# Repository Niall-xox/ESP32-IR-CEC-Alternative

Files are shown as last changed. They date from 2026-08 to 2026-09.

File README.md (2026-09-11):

# ESP32 IR Remote

A USB stick that makes your TV follow your PC's power state. The PC sleeps, the
TV turns off. The PC wakes, the TV turns on.

It is a replacement for HDMI-CEC on machines where CEC does not work — which is
most PCs. If you use a TV as a monitor and are tired of reaching for the remote
every time the machine wakes, this fixes that.

```
  PC                                  ESP32-S3 stick               TV
  ──                                  ─────────────                ──
  daemon  ──── USB HID ────────────►  firmware  ──── IR LED ────►
  (background service)                (Arduino)      (infrared)
```

A small background service on the PC watches for power events and sends `ON` or
`OFF` over USB. The stick blinks the matching infrared code at the TV, exactly
as the TV's own remote would. The stick appears as a standard USB HID device, so
there is no driver to install on any OS.

**The rule it follows:** the TV mirrors what your PC's own screen is doing. If
the display is on, the TV is on. If the display sleeps, blanks or shuts down,
the TV goes off.

---

## Status

Working and in daily use, but not yet released — read this before relying on it.

| | |
|---|---|
| **Linux** | Well tested. Sleep, wake, shutdown and boot all verified on hardware |
| **Windows** | Builds and runs as a service, tested less. Some paths unverified |
| **TV profiles** | LG is verified on real hardware. Samsung, Sony and Toshiba are derived from published code databases but **untested** |
| **Releases** | None tagged yet. Build from source for now |
| **USB ID** | Currently `1209:0001`, a shared *test* ID. A permanent one will be applied for; see [`brief.md`](brief.md) §2 |

---

## Hardware

| Part | Notes |
|---|---|
| **ESP32-S3 SuperMini** | Must be an S3 or S2 — native USB is required. A classic ESP32, ESP8266 or C3 **will not work** |
| **KY-005 IR LED module** | Any 940nm IR LED module. A bare LED with a resistor works too |
| **SSD1306 OLED, 128×32, I²C** | Optional but recommended — it is how you see which profile is active |
| **Momentary push button** | Any. Wired to ground; the internal pull-up is used |

### Wiring

| Signal | GPIO |
|---|---|
| IR LED data | 4 |
| OLED SDA | 2 |
| OLED SCL | 3 |
| Button | 5 → GND |

The OLED is addressed at `0x3C`. All pins are set in `firmware/src/main.cpp` — a
different board only needs those four constants changed.

### Enclosure

FreeCAD sources are in `hardware/`. `ESP32-Remote-Housing.FCStd` is the editable
master; the `.step` files are supplier models of the components, for fit
checking. Mesh exports are not tracked — export your own STL from the FCStd.

---

## Flashing the firmware

Needs [PlatformIO](https://platformio.org/install/cli).

```bash
git clone https://github.com/Niall-xox/ESP32-IR-CEC-Alternative
cd ESP32-IR-CEC-Alternative/firmware

pio run -t upload      # the firmware
pio run -t uploadfs    # the web config UI — needed once
```

Both steps are required on a fresh board. `uploadfs` writes the configuration
page into the stick's filesystem; without it the web UI will 404.

Some boards need a button combination to enter download mode before flashing,
and do not leave it automatically afterwards — if the device does not reappear
after `upload`, press reset or replug it.

> **`uploadfs` erases saved profiles.** It rewrites the whole filesystem, so any
> IR codes you have entered are lost and the defaults come back. That is useful
> for a clean slate and unwelcome otherwise. Firmware-only updates (`upload`)
> leave your profiles alone.

---

## Installing the daemon

### Linux — from source

```bash
cmake -B daemon/build -S daemon -DCMAKE_INSTALL_PREFIX=/usr
cmake --build daemon/build
sudo cmake --install daemon/build
```

Requires `sdbus-c++` **2.x**, `hidapi` and `libudev` (the development package —
the library itself ships with systemd, so it is already installed).

> **`-DCMAKE_INSTALL_PREFIX=/usr` is not optional.** The default prefix is
> `/usr/local`, which puts the udev rule in `/usr/local/lib/udev/rules.d/` and
> the service in `/usr/local/lib/systemd/system/`. Neither udev nor systemd
> looks in those directories, so the install appears to succeed and then the
> daemon cannot open the device and `systemctl enable` cannot find the unit.

Then create the service account the unit runs as, and let udev pick up the new
rule:

```bash
sudo groupadd --system esp32ir
sudo useradd --system --no-create-home --shell /usr/sbin/nologin \
             --gid esp32ir esp32ir
sudo udevadm control --reload-rules
sudo udevadm trigger --subsystem-match=hidraw --action=add
sudo systemctl enable --now esp32-ir-remote
```

Check it worked — the stick's node should be group `esp32ir`:

```bash
ls -l /dev/hidraw*
journalctl -u esp32-ir-remote -f
```

### Linux — packages

`.deb` and `.rpm` are built for each release, and handle the account, udev rule
and service for you.

> **The `.deb` needs sdbus-c++ 2.x, which Ubuntu 24.04 LTS does not have** — it
> ships 1.4.0. The package installs on Debian 13+ and Ubuntu 25.04+. On 24.04,
> build from source.

**Arch** builds from source on your machine:

```bash
cd daemon/packaging && makepkg -si
```

This fetches the `v$pkgver` git tag, so it only works once a release has been
tagged — see *Status* above.

**NixOS** — add the flake and enable the module:

```nix
inputs.esp32-ir-remote.url = "github:Niall-xox/ESP32-IR-CEC-Alternative";

# then
imports = [ inputs.esp32-ir-remote.nixosModules.default ];
services.esp32-ir-remote.enable = true;
```

The module declares the user, udev rule and service for you.

### Windows

Needs Visual Studio Build Tools and `hidapi` from vcpkg.

```powershell
cmake -B daemon/build -S daemon `
      -DCMAKE_TOOLCHAIN_FILE=<vcpkg>/scripts/buildsystems/vcpkg.cmake
cmake --build daemon/build --config Release
```

Then from an **elevated** PowerShell:

```powershell
powershell -ExecutionPolicy Bypass -File .\daemon\packaging\windows\install-service.ps1 `
           -BinaryPath <path>\esp32-ir-daemon.exe
```

The daemon must run as a Windows Service — a normal program is not sent power
events at all. The installer registers it, sets restart-on-failure and creates
the log directory. Logs go to `C:\ProgramData\ESP32IRRemote\daemon.log`.

To check the stick is reachable without installing anything, run the binary with
`--console`.

---

## Using it

### The button

One button, four gestures, by how long you hold it:

| Hold | Result |
|---|---|
| Tap | Wake the screen. Tap again to switch to the next TV profile |
| ~1–4 s | Nothing — a bar fills, one block per second. Let go to cancel |
| **4–7 s** | **Enter or leave wireless config mode** |
| 7–16 s | Nothing — the reset bar fills. Let go to cancel |
| **Past 16 s** | **Factory reset** — restores the default profiles |

When the screen is off, the first tap only wakes it; the *next* tap changes
profile. That stops a blind press in the dark silently switching TVs.

### The screen

Shows the active profile, `TV On` / `TV Off` when a command arrives, and
`Not Configured` if the selected profile has no IR code. It blanks after two
seconds unless you turn on "display always on" in the web UI.

### Configuring it

Hold the button for 4–7 seconds. The stick starts its own WiFi access point:

- **Network:** `ESP32-IR-Remote`
- **Password:** `irremote123`
- **Address:** shown on the OLED

Connect and open that address in a browser. You can add, edit and delete TV
profiles, set the active one, toggle the always-on display, and factory reset.
Hold the button 4–7 seconds again to exit — power syncing keeps working while
the config page is up.

---

## TV profiles and IR codes

A **profile** is one TV: a name, an IR protocol, and two codes — one to turn the
TV on, one to turn it off. Four ship by default, and all four transmit:

| Profile | Protocol |
|---|---|
| LG | NEC |
| Samsung | Samsung |
| Sony | Sony |
| Toshiba | NEC |

If your TV is not listed, add it through the web UI. You will need two things:
the **protocol** and the two **codes**.

### Discrete codes, not toggle codes

This is the part that trips people up. Most remotes send a single *toggle* code
for power — press it and the TV flips state. That is no use here: if the TV and
PC ever fall out of sync, every command makes it worse.

You need **discrete** codes — a separate "power on" and "power off". Most TVs
understand them even though their own remote never sends them, which is why you
have to look them up rather than copy them off the remote in front of you.

### Where to find them

[**irdb**](https://github.com/probonopd/irdb) is the best starting point. Browse
`codes/<Brand>/TV/` and look for `POWER ON` and `POWER OFF` entries:

```
POWER ON/OFF,Sony12,1,-1,21
POWER ON,Sony12,1,-1,46
POWER OFF,Sony12,1,-1,47
```

[**RemoteCentral**](https://files.remotecentral.com/library/index.html) has
curated discrete codes for brands irdb lacks.

Two warnings from experience. **Some brands have no discrete codes at all** —
TCL and Hisense are the notable ones, which is why they are not shipped as
profiles. And **never put a toggle code in both fields**; the TV would flip on
every single command.

Converting a database entry into the hex the firmware wants is fiddly. The
method, including how to check a code before trusting it, is written up in
[`brief.md`](brief.md) under *Where IR codes come from*.

---

## Troubleshooting

**The daemon says "ESP32 not connected".** Check the stick enumerates —
`lsusb` should show `1209:0001`. On Linux, check `/dev/hidraw*` for a node owned
by group `esp32ir`; if it is `root:root`, the udev rule has not been applied.
Replug the stick after installing.

**The TV does nothing but the daemon reports success.** The IR code was
transmitted but your TV did not accept it — usually the wrong profile, or codes
that do not match your model. Try aiming the stick directly at the TV's sensor;
IR needs line of sight.

**The screen says `Not Configured`.** The active profile has no code for that
direction. Add one through the web UI.

**Nothing happens on sleep.** Check the service is running:
`systemctl status esp32-ir-remote`, or on Windows look at
`C:\ProgramData\ESP32IRRemote\daemon.log`.

---

## Licence

**GPL-3.0-or-later.** See [LICENSE](LICENSE).

This covers everything in the repository, including the enclosure design in
`hardware/`.

Built on these, with thanks:

| Project | Licence |
|---|---|
| [IRremoteESP8266](https://github.com/crankyoldgit/IRremoteESP8266) | LGPL-2.1 |
| [ArduinoJson](https://arduinojson.org/) | MIT |
| [Adafruit SSD1306 / GFX](https://github.com/adafruit/Adafruit_SSD1306) | BSD |
| [hidapi](https://github.com/libusb/hidapi) | BSD / GPL-3 / HIDAPI |
| [libudev](https://github.com/systemd/systemd) (systemd) | LGPL-2.1 |
| [sdbus-c++](https://github.com/Kistler-Group/sdbus-cpp) | LGPL-2.1 |
| [irdb](https://github.com/probonopd/irdb) | IR code database |

---

## More detail

[`brief.md`](brief.md) is the working document — how the two halves talk to each
other, why the design decisions were made, what is verified and what is not, and
what is still outstanding. Read that before changing anything.

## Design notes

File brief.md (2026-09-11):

# ESP32 IR Remote — Project Brief

A USB stick that makes a TV follow a PC's power state. The PC sleeps, the TV
turns off. The PC wakes, the TV turns on. It is a replacement for HDMI-CEC on
machines where CEC does not work, which is most PCs.

This file is the single source of truth for how the project works and where it
stands. It is meant to be read start to finish in about fifteen minutes.

---

## 1. The shape of the thing

Two pieces of software, one cable between them.

```
  PC                                  ESP32-S3 stick                TV
  ──                                  ─────────────                 ──
  daemon  ──── USB HID ────────────►  firmware  ──── IR LED ─────►
  (a background service)              (Arduino)      (infrared)
```

**The daemon** is a small background program on the PC. Its only job is to
notice power events — sleep, wake, shutdown, boot — and send the word `ON` or
`OFF` down the USB cable.

**The firmware** runs on the ESP32. It listens on USB, and when it hears `ON` or
`OFF` it blinks the matching infrared code at the TV, exactly the way the TV's
own remote would. It also drives a small OLED screen and one button, and can put
up a WiFi configuration page.

Neither side knows anything about the other beyond those two words and a reply.

### Where things live

```
README.md  LICENSE  VERSION  brief.md  flake.nix
firmware/          the ESP32 side — src/, data/ (the web UI), platformio.ini
daemon/            the PC side — src/, packaging/, CMakeLists.txt
hardware/          FreeCAD enclosure and supplier part models
tools/hid-test/    a minimal HID echo, for when a board will not talk at all
.github/workflows/ builds both halves on every push; packages on a v* tag
```

`VERSION` sits at the root rather than under `daemon/` because the two halves
share a wire protocol and must ship together — there is one version and it
belongs to the device. `CMakeLists.txt`, `flake.nix` and `PKGBUILD` all read it
from there.

No path in the repository contains a space, which is deliberate: every script,
CMake path and CI step would otherwise need quoting, and the one that gets
forgotten fails in a way that is tedious to trace.

### The one idea the whole project rests on

**The TV mirrors what the PC's own screen is doing.**

That is the rule, and everything else follows from it. If the PC's display is
on, the TV should be on. If the display goes off — because you asked it to,
because the machine idled out, because it went to sleep or shut down — the TV
should be off. It is the same behaviour a CEC-connected display gives you, which
is the point: this device exists because CEC usually is not available on a PC.

### Why USB HID and not a serial port

HID (Human Interface Device) is the USB class that keyboards and mice use. The
advantage is that **every OS already has a driver for it**. Plug the stick in
and it works — no COM port to pick, no driver to install, nothing to sign on
Windows. That is why the project moved from serial to HID.

The cost is that the ESP32 has to have native USB hardware. The ESP32-S3 does,
and so does the S2. The ESP32-C3 does **not** (its USB controller only does
serial/JTAG, not arbitrary HID), and neither do the classic ESP32 or the
ESP8266. A serial version existed once and was removed; git history has it if
it is ever wanted again — see §11.

---

## 2. Hardware

| Part | Notes |
|---|---|
| ESP32-S3 SuperMini | Native USB. Any S3 board works; pins are set in code, not by the board profile. |
| KY-005 IR LED module | On GPIO 4. |
| SSD1306 OLED, 128×32, I²C | SDA GPIO 2, SCL GPIO 3, address 0x3C. |
| Push button | GPIO 5, to ground (uses the internal pull-up). |

CAD for the enclosure is in `hardware/`. The `.FCStd` is the editable master;
`.stl` exports are deliberately not tracked in git.

### The USB identity, and why it is `1209:0001`

Every USB device announces a **vendor ID** and a **product ID**. Vendor IDs come
from the USB-IF and cost real money. `0x1209` is **pid.codes**, a vendor ID held
in trust for open-source hardware and given out free; `0x0001` under it is their
designated **test PID**, for a device that has not been allocated one of its own
yet. Getting a real product ID is therefore a **PID-only** change — the vendor
half never moves.

**The caveat, in their words.** pid.codes state that `1209:0001` "is reserved
for use in private testing. Anyone may assign it to their device while they're
testing in-house, but it MUST NOT be used on any device that will be
redistributed, sold, or manufactured."

That is a prohibition, not a preference — and it binds on redistributing a
**device**. A GitHub Release here ships daemon packages, not hardware, and the
only stick carrying `1209:0001` is the author's own. Publishing on it was
weighed and accepted on that basis (§9), and stops being defensible the moment
sticks are handed to other people.

**Applying is not blocked on anything.** pid.codes want only a public source
repository under an open-source licence, which now exists — so the pull request
can go in at any time. PIDs `0x0000`–`0x1FFF` are reserved, so the allocated
number will be `0x2000` or above. Do not substitute a made-up number while
waiting: that squats on a registry which may legitimately assign it to somebody
else, in the namespace you are about to ask a favour from.

The value lives in **five** hand-kept places, which must change together:

| File | Spelling |
|---|---|
| `firmware/src/main.cpp` | `0x1209` / `0x0001` |
| `daemon/src/main.cpp` | `0x1209` / `0x0001` |
| `daemon/99-esp32-ir-remote.rules` | `"1209"` / `"0001"` (lowercase, no `0x`) |
| `daemon/packaging/windows/install-service.ps1` | `"1209"` / `"0001"` |
| `daemon/packaging/windows/verify-windows.ps1` | `"1209"` / `"0001"` |

Five copies is itself the argument for generating them from one source — §9.

---

## 3. The conversation over USB

Every exchange is one message and one reply, in fixed-size 64-byte packets.

**PC → ESP32:** `[sequence byte][ "ON" or "OFF" ][zero padding...]`

**ESP32 → PC:** `[same sequence byte][ "ACK" or "ERR" ][zero padding...]`

The **sequence byte** is a counter that increments on every command (1…255, then
back to 1). The reply carries the same number back, and the daemon ignores any
reply carrying a different one.

It exists to catch one specific race. The daemon sends `OFF`; USB is
re-enumerating, so the reply is slow; the daemon gives up and reports failure.
The ESP32 *did* receive it, transmits, and queues an `ACK` that is now in
flight. The next event sends `ON` — and without the sequence byte the daemon
would read that stale `ACK`, believe `ON` was confirmed, and log a success that
never happened. One byte on the wire prevents it.

`ACK` means **the infrared signal was actually transmitted**. `ERR` means it was
not, which in practice means the active profile has no code stored for that
direction. Both are useful: the daemon treats them the same way (the command
failed), but `ERR` arrives instantly and says *why*, instead of looking
identical to a broken cable for two seconds.

### One timeout, and failing fast when nothing is plugged in

A send gets **2 seconds** — total, covering opening the device, any retried
write, and waiting for the reply. There is one number, in
`HIDTransport.cpp`, and nothing else tunes it. A healthy round trip takes well
under 200 ms, and every deadline an OS imposes on us is longer than 2 s.

The more important rule is what happens when the stick is **not connected**:

- **Nothing enumerated** → give up immediately. There is nothing to wait for.
- **A handle we had just stopped working** → retry until the deadline, because
  the device demonstrably exists and is probably re-enumerating.
- **A command owed to a device that has not arrived yet** → not the transport's
  problem. It waits for the arrival notification in §5, never on a timer.

That distinction is what lets you leave the daemon installed with the stick
unplugged and have sleep and shutdown behave completely normally. Without it,
the daemon sits polling for a device that will never appear, holding the machine
up every single time.

---

## 4. The firmware (`firmware/`)

Five modules, about 1,250 lines.

| File | Does |
|---|---|
| `main.cpp` | USB HID device, IR sending, the WiFi config web server, and the wiring between button, display and storage. |
| `Profiles.cpp/.h` | The TV profiles and settings, and reading/writing them to flash. |
| `Display.cpp/.h` | Everything drawn on the OLED, and the timers that blank it. |
| `Button.cpp/.h` | Turns raw pin readings into press / hold / release events. |
| `HoldTimings.h` | The four hold durations, in one place. |

### Profiles

A **profile** is one TV: a name, an IR protocol (NEC, Samsung or Sony), an ON
code, an OFF code, and a "visible" flag that controls whether the button cycles
through it.

Four ship by default, and **every one of them transmits**. Up to 32 profiles.

| Profile | Protocol | ON | OFF |
|---|---|---|---|
| LG | NEC | `0x20DF23DC` | `0x20DFA35C` |
| Samsung | SAMSUNG | `0xE0E09966` | `0xE0E019E6` |
| Sony | SONY | `0x00000750` | `0x00000F50` |
| Toshiba | NEC | `0x02FD7E81` | `0x02FDFE01` |

That is the rule for the factory default: a brand earns a place only once a
discrete on/off pair exists that covers the product line rather than one model.
A default profile that cannot work is worse than no profile, because it looks
like the device supports your TV.

**TCL and Hisense are therefore absent, not blank.** Neither publishes usable
discrete codes: TCL has only a power *toggle*, in a protocol this firmware does
not speak, and Hisense is not in irdb at all. Filling them with a toggle would
be worse still — the same code in both fields flips the TV on every command,
which is the drift discrete codes exist to prevent. Owners of those sets add a
profile through the web UI instead.

That difference is structural, not bad luck. LG, Samsung, Sony and Toshiba
design their own remotes across a whole product line, so one code set covers the
brand. TCL and Hisense are assemblers — the same model number ships as a Roku TV
in one market and a Google TV in another, with different remotes.

The *Not Configured* path still exists and still matters: it catches a
user-added profile saved with one or both codes blank.

**Changing the defaults does not change a device that has already booted.**
`Profiles::begin()` writes them only when `profiles.json` is absent, so picking
up a new default set needs a factory reset — hold the button past 16 s.
Re-flashing alone is not enough.

**Only LG is proven on hardware.** The other three are derived from corroborated
sources and cross-checked against the encoder, but nobody has pointed the stick
at a Samsung, Sony or Toshiba. Two known risks:

- **Samsung deep sleep.** There are reports that Samsung's discrete power-on
  stops working once the TV has been off for a long time — the set stops
  listening to IR. If true, that hits this project's main use case directly
  (PC wakes in the morning, TV does not). Unconfirmed, and worth being the first
  thing checked if a Samsung ever turns up.
- **Samsung's discrete pair is not in irdb**, which lists only the toggle. It
  comes from RemoteCentral instead and derives consistently to the published
  hex, but it is one source rather than two.

Codes are stored on the ESP32's own flash filesystem (LittleFS) as two JSON
files: `/profiles.json` and `/settings.json`. Writes go to a `.tmp` file first,
are length-checked, and only then renamed over the real file.

The length check is not about validating what you typed — it catches a
*truncated* write, from the flash filling up or power being cut mid-write.
Without it the atomic rename would atomically install a valid-looking but
unparseable file, and every IR code you had entered would be gone on the next
boot.

### Discrete vs toggle codes

Most TV remotes send one *toggle* code for the power button — press it and the
TV flips state. That is useless here, because if the TV and PC ever drift out of
sync every command makes it worse.

This project needs **discrete** codes: a separate "power on" code and "power
off" code. Most TVs understand them even though their own remote never sends
them, which is why the codes have to be looked up rather than copied off the
remote in front of you.

A useful consequence: repeat commands are always safe. Sending `OFF` to a TV
that is already off does nothing at all. The daemon never has to track what it
last sent, and never has to decide whether a command is redundant.

### Where IR codes come from

Kept here because finding these again from scratch is slow, and because getting
a code wrong is worse than having none.

**[irdb](https://github.com/probonopd/irdb)** is the one to reach for first —
the largest crowd-sourced database, and it stores codes as *protocol, device,
subdevice, function* rather than as raw hex, which is exactly what you need.
Browse `codes/<Brand>/TV/` and read the CSVs:

```
curl -s https://api.github.com/repos/probonopd/irdb/contents/codes/Sony/TV
curl -s https://cdn.jsdelivr.net/gh/probonopd/irdb@master/codes/Sony/TV/1,-1.csv | grep -i power
  POWER ON/OFF,Sony12,1,-1,21
  POWER ON,Sony12,1,-1,46
  POWER OFF,Sony12,1,-1,47
```

Two things that reads out at a glance: whether **discrete** on/off codes exist
at all (many brands only have a toggle), and **how many code sets** the brand
has. One code set for a whole brand means one consistent scheme and good
coverage; five means it varies by model and you should not ship a guess.

**Turning those parameters into the hex the firmware wants.** Do *not* copy hex
off a forum — convert from the protocol parameters using the same encoder the
firmware links against, so the bit ordering cannot disagree:

- NEC — `IRsend::encodeNEC(address, command)` in `ir_NEC.cpp`
- Sony — `IRsend::encodeSony(nbits, command, address, extended)` in `ir_Sony.cpp`

Both live in `firmware/.pio/libdeps/lolin_s3_mini/IRremoteESP8266/src/`. They are
small and pure, so the quickest check is to copy them into a throwaway C file and
print the values.

**Sanity-check any result two ways.** Run the brand's *toggle* code through the
same path and confirm it matches a value you can find independently — Sony's
toggle should come out `0xA90`, LG's ON should come out `0x20DF23DC`, which is
the code already proven on real hardware here. If the toggle reproduces, the
encoding is right and the discrete pair can be trusted.

**Other sources**, in rough order of usefulness:

- [RemoteCentral's discrete code library](https://files.remotecentral.com/library/index.html)
  — curated per brand, and the best source for discrete codes irdb lacks. This
  is where the Samsung discrete pair came from; irdb only lists Samsung's toggle.
- [SB-Projects protocol reference](https://www.sbprojects.net/knowledge/ir/sirc.php)
  — how the protocols are actually framed. Read this when a code looks right but
  does not work; the Sony 12/15/20-bit distinction is the classic trap.
- The Flipper Zero and LIRC remote databases, and manufacturer RS-232/IR PDFs
  (Hisense publish one) — worth a look, but model-specific far more often.

**Watch out for.** Forum hex with no protocol stated (unusable — you cannot tell
12-bit Sony from 20-bit). Single-model blog posts presented as brand-wide. And
NEC codes whose checksum does not validate: in NEC the second command byte is
the bitwise inverse of the first, so `0x…8B75` is wrong on its face because
`0x8B` inverts to `0x74`. That one check rejects a surprising amount of bad data.

### The button

One button, four things, decided by how long you hold it:

| Hold for | On release |
|---|---|
| under 0.3 s | **Press** — wake the screen; press again to cycle to the next visible profile |
| 0.3 – 4 s | Nothing (you changed your mind — the screen shows a filling bar as a countdown) |
| 4 – 7 s | **Toggle WiFi config mode** on or off |
| 7 – 16 s | Nothing (again, a bar shows how far you are) |
| held past 16 s | **Factory reset** — fires while still held, not on release |

The press behaviour has one subtlety worth knowing: when the screen is off, the
*first* press just wakes it and shows the current profile, and only the next
press cycles. When "display always on" is enabled the screen never sleeps, so
every press cycles. That is deliberate — it stops a blind press in the dark
silently changing which TV you are controlling.

All four durations live in `HoldTimings.h` and are used from there.

### The watchdog

The ESP32 has a hardware timer that reboots the chip if the firmware stops
feeding it. `loop()` feeds it on every pass, so if `loop()` ever stops running —
a hang, a deadlock, a wait that never returns — the device resets itself after
**20 seconds** and comes back working.

This matters more than it sounds. A hung stick and an unplugged stick look
identical from the PC: the daemon just sees a command that got no reply. So
without the watchdog a hang would sit there until somebody noticed the TV had
stopped following the PC — which is exactly the unreliability this device exists
to beat. A reset costs nothing: profiles live in flash, and the daemon reopens
the device on its next command.

The 20 seconds is set by the **web server**, not by anything in our own code.
Serving the config page can legitimately block for around 12 s inside one pass
of `loop()` if a browser stalls mid-request (the server waits 5 s for the
request, 5 s for data to be acknowledged and 2 s for the close). Everything else
— button, display, IR, USB — is under 200 ms. The generous margin is deliberate:
a false reset while somebody is saving IR codes would be worse than a slow one.

It is armed at the very end of `setup()`, so start-up is never watched. A hang
before that point is a bricked-at-boot device you find the moment you flash it,
and leaving setup out keeps first-boot flash formatting from having to fit
inside the timeout.

### The OLED

Shows the active profile. By default it blanks after 2 seconds; "display always
on" keeps it lit. It also shows: `TV On` / `TV Off` confirmations when a command
arrives, the two hold progress bars, `Not Configured` when a profile has no
code, and — in WiFi mode — the AP's IP address.

**The progress bars are one block per second**, and the block count is derived
from the thresholds in `HoldTimings.h` rather than written down separately — so
the hold bar has 4 blocks and the reset bar 9, and both follow automatically if
a timing changes. That makes them countable rather than merely watchable: four
blocks means four seconds.

Each bar stops one block short of full, because the moment it would complete is
the moment the screen changes — to *Release To Enter Wireless Config!* at 4 s,
and to the status screen when the reset fires at 16 s. The screen changing is
the completion signal.

### WiFi config mode

Hold the button 4–7 seconds and the ESP32 starts its own WiFi access point:

- SSID `ESP32-IR-Remote`, password `irremote123`
- Browse to the IP shown on the OLED

The page lets you add, edit, delete and reorder profiles, set the active one,
toggle "display always on", and factory reset. It is served from LittleFS
(`firmware/data/index.html`, uploaded with `pio run -t uploadfs`).

The AP is transient and user-initiated — it is not running unless you asked for
it. Power syncing keeps working normally while it is up.

---

## 5. The daemon (`daemon/`)

About 1,450 lines of C++, one binary, built with CMake. It is built around two
small interfaces, which is what keeps Linux and Windows from tangling:

- **`ITransport`** — "send this command, tell me if it was confirmed."
  `HIDTransport` is the only implementation and is shared by both platforms.
- **`IPowerMonitor`** — "watch the OS and call me when the TV should change."
  `LinuxPowerMonitor` and `WindowsPowerMonitor` implement it.

`main.cpp` picks the right monitor for the platform and connects them. That
split is why Windows support could be added later without disturbing Linux.

### Linux (`LinuxPowerMonitor`, ~235 lines)

Linux makes this easy. `systemd-logind` broadcasts `PrepareForSleep` and
`PrepareForShutdown` over D-Bus, and — crucially — lets a program take an
**inhibitor lock** that *delays* the sleep until it says it is ready.

So the sequence is honest end to end:

```
sleep requested → daemon sends OFF → ESP32 transmits IR → ACK
               → daemon releases the lock → machine sleeps
```

The TV is genuinely off before the PC goes down.

**The lock has to be taken in advance — that is the API, not a choice we made.**
`PrepareForSleep(true)` is not a request you can answer; it is an announcement
that the delay window has already opened. logind collects who holds delay locks,
*then* broadcasts, *then* waits for those specific file descriptors to close. A
program that was not already holding one is not on the list being waited for. So
the daemon takes the lock at startup and re-takes it on every wake.

**Boot is handled separately, and waits for the stick.** The daemon reaches
`multi-user.target` before the ESP32 has finished enumerating — the stick is
powered by the machine that is booting, so it is running its own `setup()` while
systemd is starting us. The `ON` it owes has nowhere to go yet.

Rather than retry on a timer, the daemon subscribes to **udev** and is told when
a matching hidraw node appears. That is the same kind of doorbell it already
uses for sleep, so `run()` waits on both at once with `poll()` rather than
`enterEventLoop()`. If the udev watch cannot be set up it falls back to
`enterEventLoop()` and the sleep path is unaffected.

**The unit sandbox has to allow `AF_NETLINK`.** The udev monitor is a netlink
socket, and `RestrictAddressFamilies=AF_UNIX` — which was correct when D-Bus was
the only socket in use — blocks it. The daemon then starts normally, takes the
inhibitor lock, handles sleep correctly, and silently loses only the boot `ON`.
It shipped that way once. Both the unit file and the NixOS module grant it now,
and the failure names itself in the log rather than reporting a generic
"unavailable". Note that the fallback makes this class of failure *invisible in
testing* unless the log is read: everything else keeps working.

Two guards decide whether that `ON` is actually sent: `systemJustBooted()` —
uptime under 3 minutes — checked at startup **and again on arrival**. The first
stops a package upgrade restarting the service at 3 a.m. from turning your TV
on. The second stops replugging the stick a week later from doing the same.

### Windows (`WindowsPowerMonitor`, ~545 lines)

Windows is harder, for two reasons.

**1. Only a Service gets power events.** A normal program does not receive
sleep or shutdown notifications at all. So the daemon registers as a Windows
Service — which the installer does for you; you never do it by hand. (This is
completely standard for PC accessories: G HUB, iCUE, Synapse, Stream Deck and
most printer software all install services.) Run the binary from a terminal with
`--console` and it just checks the ESP32 answers, then exits. That is a
debugging aid, nothing more.

**2. Windows will not wait for you on sleep.** There is no inhibitor lock
equivalent. `PBT_APMSUSPEND` is a *notification*: the machine is going down in
about two seconds whatever you do. Shutdown is the opposite —
`SERVICE_CONTROL_PRESHUTDOWN` genuinely does wait, and is the real equivalent of
the Linux lock. The installer sets that timeout to 60 s explicitly.

So the guarantee is not uniform, and that is accepted rather than solved:

| Event | Guaranteed? |
|---|---|
| Linux sleep / shutdown | Yes — inhibitor lock |
| Windows shutdown | Yes — preshutdown |
| Windows sleep | Best effort — ~2 s of grace, a send takes ~200 ms |

**What drives the decision.** The console display state, on every machine. The
daemon registers for `CONSOLE_DISPLAY_STATE` notifications: display on → TV on,
display off → TV off, dimmed → treated as on.

There is no branching on the machine's sleep model. There used to be — the
daemon probed whether the machine was classic S3, hibernate-capable or Modern
Standby, and ignored a screen blank on machines where a real suspend event was
coming. That whole apparatus is gone, because the premise was wrong: when
Windows reports "display off" it has *already blanked every display, the TV
among them*. Acting on it does not black out a screen somebody is watching — it
turns off one that is already showing black.

Suspend and resume are kept underneath as a second trigger, in case a lid-close
or an explicit Sleep ever reaches us without a display-state change first.
Duplicate commands are harmless because the codes are discrete.

Windows sees device arrival too, through `RegisterDeviceNotification`, and it is
what delivers the boot `ON` there — the display-state notification decides the
state, and arrival re-sends it if the stick was not yet present. A mid-session
replug leaves the TV alone, because the re-assert only happens within
`ARRIVAL_GRACE` of the service starting.

**That window is measured from service start, not system uptime, and the
difference matters.** Windows **Fast Startup** is on by default on 10 and 11 and
does not perform a real boot — it hibernates the kernel session and restores it
— so `GetTickCount64()` can report hours after what the user experienced as a
cold start. An uptime-based gate would skip the boot `ON` on most Windows
machines. The service genuinely did just start either way, so that is the clock
to measure against.

Linux cannot use the same trick, and does not need to. Its trigger is the daemon
starting, which *does* happen on a service restart, so it has to ask the system
how long the machine has been up. Windows' trigger is device arrival, which does
not fire on a restart. The two platforms answer different questions, which is
why the check is not shared code.

One nice consequence: `PBT_APMRESUMEAUTOMATIC` — the machine waking itself for a
maintenance task at 3 a.m. — needs no special case. The display stays off, so no
`ON` is sent. The behaviour falls out of the model instead of being hand-coded.

**Threading.** The service control handler runs on the OS's thread and must
return immediately, so it only *records* what happened and wakes a worker
thread, which does the actual sending. Linux needs none of this — sdbus-c++
dispatches signals on the one thread it is already using.

---

## 6. Rules that must not be broken

Short list, kept short on purpose. Each one, if broken, re-introduces a bug that
was already fixed once.

**The model**
- The TV mirrors the PC's display state. Anything else — suspend, resume,
  shutdown, boot — is a secondary trigger under that, not a competing policy.

**Honesty**
- `ACK` is sent only after the IR signal has finished transmitting. A `0x0` code
  answers `ERR`, never `ACK`.
- Replies are matched to requests by sequence byte, never by timing.
- A `false` from `send()` must never stop the machine sleeping or shutting down.

**Timing**
- One timeout for a whole send, and it lives in the transport. Callers do not
  get to pass a budget; earlier versions let them, and it went wrong in both
  directions.
- When no device is enumerated, fail immediately. Retrying is only ever correct
  for a device that was open a moment ago. A command owed to a device that has
  not arrived yet waits for the arrival notification, never on a timer.

**Threading**
- `HIDTransport` is single-threaded and holds no lock. On Windows only the
  worker thread touches it; a control handler records and returns. On Linux the
  udev callback runs on the same thread as the D-Bus dispatch, which is what
  keeps that true — moving the device watch onto a thread of its own would make
  a lock mandatory.

**Storage**
- Flash writes are atomic *and* length-checked. Atomically replacing a file with
  incomplete content is still corruption.
- Every index into the profile list is range-checked where it is used.

**Only one process may hold the device.** Two programs opening the same HID
device eat each other's replies — and the sequence byte cannot catch it, because
the reply is well-formed and correctly numbered, just for somebody else's
request. The workflow that causes it is the one we built: service running, then
someone runs the binary with `--console`. Linux is protected by the udev group;
Windows uses a named mutex.

**Logging must be unbuffered** (`std::unitbuf`). Otherwise the last lines before
the process is killed — including the shutdown `OFF` confirmation, the single
most useful line — are lost.

**Build and unit**
- The unit's `RestrictAddressFamilies` must keep `AF_NETLINK` alongside
  `AF_UNIX`, in both the unit file and the NixOS module. Tightening it back to
  `AF_UNIX` alone silently disables the device watch and loses the boot `ON`,
  while leaving everything else working — see §5.
- `ARDUINO_USB_MODE` must be `0`. At `1` the device enumerates as a serial port
  and the daemon never finds it.
- The flash partition table is stated explicitly. If a toolchain bump moved the
  default layout, LittleFS would relocate and every stored IR code would be lost
  on the next firmware update.

---

## 7. Building and installing

**The step-by-step lives in [`README.md`](README.md)** — bill of materials,
wiring, flashing, per-OS install and the service account. It is not repeated
here, because two copies of an install procedure drift and the README is the one
a stranger will read. What follows is only what the README does not say.

**Dependencies.** `sdbus-c++` **2.x** (1.x will not compile — the version is
asserted in `find_package` so it fails immediately rather than deep in template
errors), `hidapi`, and `libudev` for the device watch. All three are present on
any machine that can run the daemon at all, since it already requires systemd.

**The install prefix matters and is easy to get wrong.** `install()` uses
relative destinations (`lib/udev/rules.d`, `lib/systemd/system`), so the default
`/usr/local` prefix lands them in `/usr/local/lib/...` — which **neither udev
nor systemd reads**. The install reports success, then the daemon cannot open
the device and `systemctl enable` cannot find the unit. The relative paths are
themselves deliberate, because CPack rebases them when staging a package; the
cost is that a hand install has to pass `-DCMAKE_INSTALL_PREFIX=/usr`.

**Four packaging routes, one build.** `.deb` and `.rpm` come from CPack via
GitHub Actions on a `v*` tag; Arch builds from `daemon/packaging/PKGBUILD` on
the user's own machine; NixOS has a flake and a module
(`services.esp32-ir-remote.enable = true;`). All four call the project's own
`CMakeLists.txt` rather than reimplementing the build, so none of them can
drift from what a source build produces.

**Windows** needs Visual Studio Build Tools and vcpkg's hidapi, and the service
must be registered by `install-service.ps1` from an elevated PowerShell — a
plain program is never sent power events. Logs go to
`C:\ProgramData\ESP32IRRemote\daemon.log`. `verify-windows.ps1` writes a report
of what the machine is and what the daemon did, for comparing across machines.

---

## 8. Where the project stands

### Working and verified on hardware (Linux)

Sleep, wake, shutdown and boot all confirmed on NixOS, the last of them through
the udev watch. The inhibitor lock held the poweroff off until the ESP32
confirmed the IR had gone out. The uptime gate was proven both ways.
Unconfigured-profile handling was proven (Samsung selected, nothing transmitted,
`Not Configured` on screen).

**The boot sequence, from a real journal**, with the stick unplugged at power-on
and pushed in ten seconds later:

```
19:58:58.863  [transport] ESP32 not found at startup
19:58:58.965  [monitor]   Watching udev for the ESP32
19:58:58.972  [cmd]       ON FAILED — no ACK (startup)
19:58:58.972  [cmd]       ON deferred until the ESP32 appears
19:59:09.568  [monitor]   ESP32 appeared
19:59:09.758  [cmd]       ON sent and ACK received (device ready)
```

**How far behind the daemon the stick actually is: 4.5 seconds, every boot.**
Measured across three consecutive normal boots, stick plugged in throughout,
and it did not vary. This was never a rare race — the boot `ON` was being lost
every single time. Worth knowing if the design is ever revisited: any fixed
retry window would need to clear 4.5 s comfortably on this machine alone.

Filter precision was checked separately with `udevadm trigger
--subsystem-match=hidraw --action=add`, which fires an `add` for every hidraw
node. Eleven devices, exactly one `ESP32 appeared` — no false positives from
the other ten, no missed match on ours.

Sleep, wake and shutdown were re-confirmed *after* the watch was working, so
they ran through the `poll()` loop rather than the `enterEventLoop()` fallback.
Each send ACKed in ~122 ms. Idle cost of the loop is nil: 0.0% CPU, no
measurable CPU time over a hundred seconds.

### Working, less proven (Windows)

Builds in CI on every push. Has been run as a service on three machines covering
the three sleep models. Behaves correctly in the cases tested, but has had
nothing like Linux's exercise — and the display-state simplification below
changes its behaviour on S3 machines, so those need re-testing.

### Needs testing

**If the boot `ON` is ever reported missing again, read the log before anything
else.** `Watching udev for the ESP32` means the doorbell is live. `udev watch
unavailable` means the daemon has fallen back to `enterEventLoop()` and the
whole mechanism is dormant — and because the fallback keeps sleep, wake and
shutdown working perfectly, nothing else will look wrong. That exact failure
shipped once and passed a reboot-and-sleep test; §5 has the cause.

**Windows** — all five need the Windows machine:

1. **S3 machine**: an idle screen blank should now turn the TV off. It
   previously did not. The biggest behaviour change of the lot.
2. **Stick unplugged**: shutdown should be instant, where it was previously
   delayed by up to 20 s.
3. **Normal sleep/wake**: confirm the single 2 s timeout is enough.
4. **Boot with Fast Startup on** (the default): the TV should come on. This is
   what `ARRIVAL_GRACE` being measured from service start rather than uptime
   exists for, and it is the case an uptime-based gate would have silently
   broken on most machines.
5. **Replug mid-session**: the TV should *not* change state.

### Not verified

- Boot with "display always on" enabled — the status screen should be up from
  boot rather than after the first button press.
- Recovery from a corrupt `profiles.json` — the code path exists, but testing it
  means flashing a deliberately broken filesystem image. Judged not worth it.

### Known gaps

| Gap | Severity |
|---|---|
| **Test USB PID `1209:0001`.** A real vendor ID, but a *shared* test PID. Acceptable while the only stick is the author's (§2); must be replaced before any hardware reaches another person. Hand-copied into **five** files. | Medium |
| **The README Status table needs a pass before tagging.** It says "Releases: None tagged yet", which would ship inside the release contradicting itself. Its Windows and LG-only claims are true now but will age. | Low |
| **No release guard.** Any `v*` tag publishes a public Release with the packages attached. Nothing checks the version, the PID or anything else first. One mistyped `git push --tags` publishes. | Medium |
| **A hand install with the default prefix silently half-works.** `cmake --install` without `-DCMAKE_INSTALL_PREFIX=/usr` puts the udev rule and unit under `/usr/local/lib/`, which nothing reads. Documented in §7, but a `message(WARNING)` in `CMakeLists.txt` when the prefix is not `/usr` would catch it at the point of the mistake. | Medium |
| **No profile for TCL or Hisense** — no usable discrete codes appear to exist for either brand. Not fixable from a database; it needs somebody with the TV in front of them. Those users add a profile by hand. See §4. | Low |
| **Samsung, Sony and Toshiba codes are unverified on hardware.** Derived from corroborated sources and cross-checked against the encoder, but nobody has pointed the stick at one of those TVs. | Medium |
| **Linux does not watch display state.** Your screen blanks, the TV stays on. Now that the whole project is framed as mirroring the display, this is a real inconsistency rather than a design choice. | Medium |
| **Windows service runs as LocalSystem.** Linux runs unprivileged; Windows should move to LocalService to match. | Medium |
| CI does not build the firmware — only the daemon. | Medium |
| A cancelled shutdown does not re-take the Linux inhibitor lock, so the next sleep goes undelayed. Needs the cancel to land in a sub-second window; a sleep/wake cycle repairs it. | Low |
| WiFi AP password is hardcoded. Better: derive it per-device from the chip ID and show it on the OLED. | Low |
| The web server serves any file on LittleFS, including `profiles.json`. Harmless today. | Low |

---

## 9. What to do next

In the order that gets the project finished.

**Tagging is the act of publishing, not a bookmark.** `packages.yml` triggers on
any `v*` tag and puts out a **public GitHub Release** with the `.deb` and `.rpm`
attached. There are no tags yet. Everything is staged at `1.0.0`, and as of the
udev watch being verified on hardware (§8) **nothing is holding the tag back**.
The remaining items below are all improvements rather than blockers.

Releasing on the test PID was weighed and accepted — the prohibition binds on
redistributing hardware, and only daemon packages ship (§2). A real PID is
still item 2 below.

1. **Verify the new codes on real TVs** if any are within reach — Samsung, Sony
   and Toshiba are all derived rather than tested. A Samsung is the one most
   worth finding, both because it is the most common brand and because of the
   deep-sleep caveat in §4.

2. **Apply to pid.codes for a product ID** — a pull request to their repository,
   needing only a public repo with an open-source licence, so it can go in at any
   time and run in parallel with everything else. Start it early: it is reviewed
   by volunteers, so the turnaround is not yours to control. Then
   generate the five copies from one source so the count cannot go 5 → 6. See
   §2 for why a placeholder is not an acceptable substitute.

3. **Re-test Windows** against the three cases in §8, then move the service to
   LocalService. The installer already grants LOCAL SERVICE rights on the log
   directory, so the only open question is whether that account can open the HID
   device — and the vendor usage page (`0xFF00`) is not one Windows restricts,
   so it very likely can. Test with
   `sc.exe config esp32-ir-remote obj= "NT AUTHORITY\LocalService"`.

4. **Add display-state watching on Linux**, closing the inconsistency in §8.

5. Add the firmware to CI.

### Worth considering, not required

**An IR receiver.** A VS1838B costs about £1 and one more GPIO. With it, the web
UI could have a "learn" button: point your remote at the stick, press power, and
it captures the code. `IRremoteESP8266` already includes the decoder, so this is
mostly UI work. It would turn "works if you can find hex codes for your TV" into
"works for anyone" — the single biggest improvement available to the product.

---

## 10. Decisions taken, and why

Reviewed 2026-09-09. Kept as-is, with the reasoning, so they are not re-litigated:

- **The sequence byte stays.** One byte, ~6 lines, prevents a stale `ACK` being
  read as confirmation of a different command. See §3.
- **`ERR` stays.** ~7 lines, and it turns a misleading two-second timeout into
  an instant accurate log line. If it is ever removed, `ACK` must *not* start
  meaning "received" — instead make an uncoded profile unselectable, so the
  failure cannot occur.
- **The length check on flash writes stays.** It guards against truncated
  writes, not against bad user input. See §4.
- **The Windows named mutex stays.** A registered VID/PID does not address it;
  those are different problems.
- **Exact dependency pins and the explicit partition table stay.** The partition
  one protects stored IR codes across a firmware update.
- **The Linux uptime gate stays**, on the strength of the 3 a.m. unattended
  upgrade case.
- **Linux and Windows deliberately measure different clocks**, and the check is
  not shared code. Unifying them looks like an obvious tidy-up and is wrong —
  see §5. It was tried and reverted.

---

## 11. Still open

Deferred by decision, not forgotten. None of these block a release.

- **A second serial transport**, for ESP32 boards without native USB.
  `ITransport` is exactly the right seam, and the old implementation is in git
  history (removed 2026-09-09) as a starting point. But the serial I/O is not
  the work: **finding the device is.** A board without native USB is seen through a CP2102 or CH340
  bridge whose VID/PID (`10c4:ea60`, `1a86:7523`) is shared with thousands of
  unrelated devices, so there is nothing to match on. It needs either a config
  file naming the port or an identify-handshake across candidate ports, plus a
  second firmware build variant, a `dialout` udev rule, and a relaxed systemd
  sandbox. Perhaps 150 lines for the config-file version.

- **Whether the Windows service should stop retrying eventually**, rather than
  restarting forever. Currently `restart/5000` three times with a daily reset.

- **Panasonic support** — a major brand in the UK with published discrete codes,
  but Panasonic is a 48-bit protocol and `Profile.onCode` is `uint32_t`, so it
  needs the code fields widened as well as a new protocol. Explicitly dropped
  for now.

- **Display-state watching on Linux** — the last real feature gap. Deferred, not
  rejected; see §8.

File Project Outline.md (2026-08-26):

# ESP32 IR Remote — Project Outline

Working reference for the project. Covers what the device does, how the two
halves talk to each other, the rules the implementation has to keep, and how to
build it on each platform.

Not user documentation — that comes later, separately.

**Contents**

- [Overview](#overview)
- [Current status](#current-status)
- [Hardware](#hardware)
- [Architecture](#architecture)
- [Communication protocol](#communication-protocol)
- [Firmware](#firmware) — [profiles](#manufacturer-profiles) · [button & display](#button--display-behaviour) · [storage](#storage-littlefs) · [web UI](#web-ui) · [source map](#firmware-source-map)
- [Daemon](#daemon) — [power events](#power-event-detection-linux) · [cross-platform](#cross-platform-design) · [Windows](#windows-status) · [source map](#daemon-source-map)
- [Windows — in progress](#windows--in-progress) ← **current focus**
- [Invariants](#invariants)
- [Building](#building) — [firmware](#firmware-build) · [Linux](#daemon--linux) · [NixOS](#nixos) · [Windows](#windows) · [packaging](#packaging--ci) · [sdbus-c++](#the-sdbus-c-constraint)
- [Known issues and deferred work](#known-issues-and-deferred-work)
- [History](#history)

---

## Overview

A USB-connected device that synchronises a TV's power state with a connected PC,
using the TV's built-in IR remote compatibility. This replicates the behaviour of
HDMI-CEC without requiring CEC support on either device.

| PC Event | TV Action |
|---|---|
| Power on from shutdown | Turn TV on |
| Wake from sleep | Turn TV on |
| Shutdown | Turn TV off  |
| Enter sleep | Turn TV off  |

**On Windows the display coming on also turns the TV on**, on every machine: a
screen lighting up is the most direct evidence there is that somebody is at the
PC, and on a Fast Startup machine it is the only route to an ON at boot.

**The screen *blanking* turns the TV off only where nothing else can** — a
Modern Standby machine, which never enters a classic suspend and so raises no
usable suspend event. A machine that reports classic S3 gets its OFF from the
suspend event instead, and an idle screen blank is ignored there, so the
behaviour matches Linux. The daemon reads which kind of machine it is at startup
and says so in its log. See
[driving from display state](#driving-from-display-state).

That split matters because the divergence is not free. On a Modern Standby
machine the TV switches off when the screen blanks, including under somebody who
is still sitting there watching something that failed to assert
`ES_DISPLAY_REQUIRED`. That is a real cost accepted only where the alternative
is a TV that never switches off at all.

Existing solutions (e.g. Wake-on-LAN, network-based control) are unreliable and
dependent on network state. This device operates at the USB layer, making it
robust and network-independent.

---

## Current status

**Working and verified on hardware:** USB HID transport with ACK-based inhibitor
release, multi-manufacturer profiles on LittleFS, the button, the OLED, WiFi
config mode and the web UI. Deployed on NixOS via the flake module and confirmed
running as an unprivileged service.

**Second hardening pass — verified on hardware 2026-08-24.** The sequenced
protocol, the uptime gate, the unconfigured-profile guard and the full
sleep/wake/shutdown/boot cycle have all been exercised against the real device
and daemon. Two items remain untested, neither on the power-sync path — see
[Still unverified on hardware](#still-unverified-on-hardware).

**Windows — implemented for all three power models 2026-08-26, none of it run.**
The daemon builds and links, and one binary now covers classic S3, hibernate
(S4) and Modern Standby (S0 low power idle). It reports which of the three the
machine is at startup, reacts to the ESP32 arriving and leaving, and measures
how much of a suspend's grace period each send actually consumed. The service
has still never been installed, so every runtime assumption in it remains
unproven. Pick it up at [Resume here](#resume-here).

**Reviewed against the project's aims 2026-08-26, and two things changed.** The
brief had grown detailed enough to be internally consistent while drifting from
what the [Overview](#overview) table promises. Reading it back against those four
rows found an idle screen blank turning the TV off on machines that had a better
signal available, and a screen blank inheriting a suspend's 1500ms deadline
while nothing was waiting for it. Both are fixed, in the brief and in the code;
both are Windows-only and remain unrun like the rest of it. The full reasoning is
under [the reversals](#five-decisions-the-sanity-check-reversed).

**Firmware flashed 2026-08-26, and Linux re-verified on it.** A full S3
sleep/wake cycle behaves exactly as it did before — see
[the second-pass table](#verified-on-hardware--second-pass).

The USB suspend recovery did **not** fire during that cycle, which the previous
version of this brief predicted it would. The prediction was wrong and the
reason is worth keeping: see
[what Linux actually did](#what-linux-actually-does-across-a-suspend). The fix
therefore remains unexercised on either platform.

**Three things block any public release:**

1. Registered VID/PID — currently placeholder `1234:5678`.
2. Confirmed discrete IR codes for Samsung, Sony, TCL and Hisense.
3. A LICENSE and a README — both packages already declare MIT.

Verification detail and the full outstanding list are in
[Known issues and deferred work](#known-issues-and-deferred-work).

---

## Hardware

- **ESP32-S3 SuperMini** — microcontroller running the firmware
- **IR LED** — transmits IR signals to the TV (GPIO 4)
- **OLED display (128×32, SSD1306)** — status feedback (SDA: GPIO 2, SCL: GPIO 3)
- **Tactile button** — profile cycling, config mode, factory reset (GPIO 5, GND)

**On the board name.** PlatformIO has no board definition for the ESP32-S3
SuperMini, so `platformio.ini` builds for `lolin_s3_mini` as a close-enough
match — same ESP32-S3 target, and the pin assignments above are set explicitly
in the firmware rather than inherited from the board definition. This is
deliberate, not an oversight. The CAD directory likewise models the housing
around an `ESP32-S3_Zero.step`, another similarly-sized S3 board used as a
stand-in.

### CAD sources

`3D modeling/` holds `ESP32-Remote-Housing.FCStd` — the FreeCAD master, and the
only housing file that is tracked — alongside `.STEP` component models for the
board, IR transmitter, OLED and button.

`.FCBak` and `.stl` are gitignored. FreeCAD writes a backup beside the master on
every save, and mesh exports are derived files that go stale the moment the model
changes; re-export from the `.FCStd` rather than trusting a committed one.
`git add -f` if a specific export ever needs shipping.

---

## Architecture

Two components:

**PC daemon** — a background process that monitors system power events and sends
commands to the ESP32 over USB. C++17, cross-platform.

**ESP32 firmware** — receives commands over USB HID, transmits the IR signal for
the active manufacturer profile, updates the OLED, and answers ACK or ERR.

---

## Communication protocol

### Wire format

Transport is USB HID, 64-byte vendor-defined reports. Both directions share one
payload layout:

| Byte | Daemon → ESP32 | ESP32 → Daemon |
|---|---|---|
| `[0]` | sequence, 1–255, never 0 | the same sequence, echoed unchanged |
| `[1..]` | NUL-terminated command | NUL-terminated response |

| Command | Response | Action |
|---|---|---|
| `ON`  | `ACK` | Fire IR ON code for active profile |
| `OFF` | `ACK` | Fire IR OFF code for active profile |
| `ON` / `OFF`, code unset | `ERR` | Active profile's code for that direction is `0x0` — nothing transmitted |
| unknown | `ERR` | Unknown command received |

- IR dispatch is synchronous. ACK is sent only after the signal has fully
  transmitted, so the daemon can release its inhibitor lock the instant it
  arrives. No fixed delays anywhere in the pipeline.
- The sequence byte is echoed, never interpreted — the ESP32 needs no state to
  support it. It exists so the daemon can tell a reply to *this* command from a
  late reply to an earlier one.
- The daemon discards any reply whose sequence does not match, and keeps waiting
  for the right one until its budget expires.
- Communication is daemon-initiated only. The ESP32 never sends unsolicited
  reports.

### Version lockstep is deliberate

**Firmware and daemon must be updated together**, and the protocol carries no
compatibility path for a mismatched pair. This is a decision, not an oversight —
please do not "fix" it without reading the rest of this section.

Both halves ship together and the project is pre-release, so there is no
installed base to strand. Carrying fallbacks for versions nobody is running
would be machinery earning nothing, and it has a real cost beyond the code:
a compatibility path makes "the reply could not be correlated" into a silent,
accepted state. That is the same category of defect the sequence byte exists to
eliminate — a weaker guarantee that still reports success. Lockstep keeps the
guarantee unconditional, which is both easier to reason about and easier to keep
true.

A mismatch is loud rather than mysterious. The daemon logs:

```
[transport] Discarding unmatched reply (seq 79, expected 3) — stale reply,
            or firmware too old for the sequenced protocol
[transport] No response received for command: ON
```

That names the cause directly, which is the genuinely useful part of
compatibility — knowing *why* it stopped — at no cost. Reflash and it is fixed.

**What would change the calculus:** the daemon updating independently in the
field. It installs from a package and updates whenever the distribution ships
one; the firmware is flashed by hand over USB and in practice hardly ever is.
Once there are users who upgrade one without the other, a flag day stops being
acceptable and the wire format needs an additive path — new fields placed where
an older peer skips them, behind a string terminator or a field it already
ignores, with a reserved value meaning "absent".

**Trigger to revisit:** the first packaged release that reaches someone else.
Not before.

### Timing budget

`send()` runs inside a sleep or shutdown handler while a logind delay inhibitor
is held, and logind stops waiting after `InhibitDelayMaxSec` — **5 seconds by
default**. Every step of a send therefore draws on one shared 4-second budget:
device open, reopen-after-write-failure, and the ACK wait.

`SEND_BUDGET` in `HIDTransport.cpp` is the single knob. Raising it above 5s
reintroduces the problem regardless of what the individual timeouts say.

### USB device identity

The daemon finds the device by VID/PID — no port numbers or paths.

| Field | Value | Notes |
|---|---|---|
| VID | `0x1234` | Placeholder — replace before any release |
| PID | `0x5678` | Placeholder — replace before any release |
| Product name | `ESP32 IR Remote` | Shown in system device list |
| Manufacturer | `ESP32-IR-CEC` | Shown in system device list |

These must match in **five** places:

| File | Form |
|---|---|
| `firmware/src/main.cpp` | `0x` hex |
| `daemon/src/main.cpp` | `0x` hex |
| `99-esp32-ir-remote.rules` | lowercase hex, no `0x` |
| `packaging/windows/install-service.ps1` | hex, no `0x`, as `-VendorId` / `-ProductId` defaults |
| `packaging/windows/verify-windows.ps1` | hex, no `0x`, same defaults |

The last two are Windows-side and newer than the rest. The installer needs the
pair to find the device's registry key and disable USB selective suspend on it;
the verification script needs it to report whether the device is present and
what those registry values currently say.

That the count has gone from three to four to five is the argument for a single
generated header rather than five hand-kept copies — and the reason the
placeholder pair is listed as
[blocking release](#blocking-release) rather than as a tidy-up. Five places is
where "change them together" stops being advice and starts being a defect
waiting for the one that gets missed.

For open-source release, a free registered pair is available from
[pid.codes](https://pid.codes). Commercial release needs a USB-IF VID.

---

## Firmware

### Manufacturer profiles

IR codes are stored per-profile in `/profiles.json` on LittleFS:

- `name` — display name (e.g. `LG`)
- `protocol` — `NEC`, `SAMSUNG` or `SONY`
- `on_code` / `off_code` — discrete power codes
- `visible` — whether the profile appears in the button cycle

Discrete on/off codes are preferred over toggle codes: they guarantee the correct
TV state regardless of any prior state drift.

Defaults are hardcoded in firmware and written to LittleFS on first boot. Factory
reset rewrites from these.

| Profile  | Protocol | ON Code | OFF Code | Notes |
|---|---|---|---|---|
| LG | NEC | `0x20DF23DC` | `0x20DFA35C` | Confirmed working on LG C2 |
| Samsung  | SAMSUNG  | placeholder  | placeholder  | |
| Sony | SONY | placeholder  | placeholder  | |
| TCL | NEC | placeholder  | placeholder  | |
| Hisense  | NEC | placeholder  | placeholder  | |

`0x20DFB34C` was tested as an LG ON code but triggers a smart TV network prompt
on the C2 — it maps to a smart home power-on mode, not plain power-on.

**`0x0` means "not configured", and this is enforced:**

- Firmware refuses to transmit, answers `ERR`, OLED shows `Not Configured`
- Daemon logs `FAILED — no ACK, TV state not changed`
- Web UI shows a `No IR code` badge

Filling in real codes needs no code change — the guard simply stops firing.

The list is capped at 32 profiles (`Profiles::MAX_PROFILES`), enforced on load
and on POST.

### Button & display behaviour

Thresholds (300ms / 5s / 8s / 23s) live in `HoldTimings.h`, shared by `Button`
(which decides what a hold means) and `Display` (which draws bars spanning the
same windows).

- **Press** — released within 300ms
- **Hold** — held beyond 300ms

#### At boot

Status screen drawn as soon as display and profiles are up. With always-on
enabled it stays; with it disabled it shows for 2 seconds as a boot confirmation
then turns off.

#### Normal operation — always-on disabled (default)

| Event | Behaviour |
|---|---|
| Press 1 (display off) | Show `Profile: LG`, 2s timer, then off |
| Press 2+ (within timer) | Cycle to next visible profile, reset timer |
| IR command | Show `TV On` / `TV Off`, off after 2s |

#### Normal operation — always-on enabled

OLED on continuously showing `Profile: LG`.

| Event | Behaviour |
|---|---|
| Press 1 | Show status screen |
| Press 2+ | Cycle to next visible profile |
| IR command | Show `TV On` / `TV Off`, back to status after 2s |

#### Hold behaviour (both modes)

- **300ms** — progress bar appears, text above:
  ```
  Enter Wireless Config Mode?
  [▓▓░░░]  ← 5 blocks, 1 per second
  ```
- **Released before 5s** — status screen, next press cycles
- **5s** — bar full, text changes to `Release To Enter / Wireless Config!`
- **Released 5s–8s** — enter wireless config mode
- **Held to 8s** — factory reset screen:
  ```
  Hold To Factory Reset
  [▓▓▓░░░░░░░░░░░░░░░░░]  ← 15 segments, 1 per second
  ```
- **Released 8s–23s** — cancelled, status screen
- **Held to 23s** — factory reset triggers automatically

Whenever a hold is cancelled or completes, the display returns to the status
screen and the next press cycles profiles.

#### Wireless config mode

OLED on continuously (cannot be disabled):
```
Profile: LG
WiFi: Active
192.168.4.1
```

| Event | Behaviour |
|---|---|
| Press 1 | Show status screen |
| Press 2+ | Show `Hold Button to Exit / Wireless Mode to / Switch Profiles` for 2s |
| Hold | Same bars, but `Exit Wireless Config Mode?` and `Release To Exit` |
| Released 5s–8s | Exit config mode, return to normal operation |
| Held to 23s | Factory reset |

Also exits via the web UI's `Save and Exit`.

### Storage (LittleFS)

`/profiles.json` — array of profile objects:
```json
[
  { "name": "LG", "protocol": "NEC", "on": "0x20DF23DC", "off": "0x20DFA35C", "visible": true }
]
```

`/settings.json`:
```json
{ "active_profile": 0, "display_always_on": false }
```

Both written from hardcoded defaults on first boot; factory reset rewrites both.

**Writes are atomic and length-checked.** Serialised to `<name>.tmp`, then
renamed over the destination, and only promoted if the bytes written match
`measureJson()`. The rename makes the *replacement* atomic; it does nothing
about whether the contents are complete, and a full or failing flash returns a
partial write with a non-zero count. A stray `.tmp` after power loss is harmless
and overwritten by the next save.

### Web UI

Served from LittleFS at `192.168.4.1` when wireless config mode is active. AP is
`ESP32-IR-Remote` / `irremote123`.

**Profiles** — view, select active, add, edit, delete, show/hide from the button
cycle, `No IR code` badge on unset profiles. Deleting the *active* profile falls
back to the preceding entry and says which profile is now active.

**Settings** — display always on toggle.

**Actions** — Save · Restore · Factory Reset · Save and Exit.

**Validation** — saving is refused, with the offending profile named, if a
profile has an empty name or a code that is not hex (`0x20DF23DC` or bare
`20DF23DC`, up to 32 bits). The firmware parses an unusable code as `0x0` and
treats that as unconfigured, so a typo cannot corrupt anything — but it would
produce a profile that silently declines to transmit, and the browser is where
the user can still see what they typed.

### Firmware source map

```
firmware/
  platformio.ini
  data/index.html                (web UI, served from LittleFS in WiFi mode)
  src/
    main.cpp                     (HID setup, IR dispatch, button callbacks, WiFi lifecycle)
    Button.h / .cpp              (non-blocking press/hold detection, debounced)
    Display.h / .cpp             (OLED state machine, timer-based expiry)
    Profiles.h / .cpp            (LittleFS profile + settings storage)
    HoldTimings.h                (hold thresholds, shared by Button and Display)
```

| File | Notes |
|---|---|
| `platformio.ini` | Platform, libraries and partition table all pinned exactly. |
| `main.cpp` | Refuses to transmit an unset code and answers `ERR`. Echoes the protocol sequence byte. |
| `Profiles.h/.cpp` | `toJson`/`fromJson` are the only places profiles cross the JSON boundary, so the on-disk format and the web API cannot drift. `getActive()` falls back to a built-in profile if storage is unavailable. |

---

## Daemon

### Power event detection (Linux)

Uses the **systemd-logind D-Bus API** — the same mechanism GNOME and KDE use.
Subscribes to `PrepareForSleep` and `PrepareForShutdown` on
`org.freedesktop.login1`.

**Inhibitor lock lifecycle:**

1. Acquired at construction, held continuously.
2. On a sleep/shutdown signal the callback runs to completion — which means the
   ESP32 has ACKed — then the lock is released and systemd proceeds.
3. Re-acquired on resume (`PrepareForSleep(false)`), ready for the next sleep.

`PrepareForShutdown(false)` — a scheduled shutdown being cancelled — is
deliberately not handled. See
[Known issues](#known-issues-and-deferred-work) for why.

**Startup ON is gated on uptime.** The service starting only implies a boot if
the machine actually just booted — `Restart=on-failure`, package upgrades and
`systemctl restart` all start the service too. The daemon reads `/proc/uptime`
and skips the ON if the system has been up longer than 180 seconds. The window
is deliberately generous: a slow machine that misses it merely fails to turn the
TV on, which the user can undo with their remote, whereas a tight window would
make that the common case.

### Cross-platform design

Two platform-specific concerns sit behind abstract interfaces:

```
TvCommand       — { bool on; const char* reason; milliseconds budget; }
IPowerMonitor   — raises OnCommand(TvCommand),
                  and OnDeviceChange where the platform reports it
ITransport      — bool send(cmd, budget = 0)
                  void invalidate()
```

`main.cpp` only ever touches these. Platform implementations are compiled in or
out by CMake.

**One callback, not three.** `OnSleep`, `OnWake` and `OnShutdown` were separate,
and the send budget came from two extra virtuals on `IPowerMonitor`. That put
the deadline on an event *class* rather than on the event, and the difference
stopped being academic the moment Windows began driving the TV from display
state — see the fifth row of
[the reversals](#five-decisions-the-sanity-check-reversed). Both the reason and
the deadline are known only to whatever raised the event, so they travel with it.

`OnDeviceChange` remains defaulted, so a platform with no device notification
implements nothing and the transport goes on discovering a vanished device by
failing a write. Linux takes that default. Linux also states a zero budget on
every command — logind holds the system for `InhibitDelayMaxSec` for sleep and
shutdown alike, and the transport's default is already sized against it.

| Concern | Linux | Windows |
|---|---|---|
| Power events | sdbus-c++ / systemd-logind | Win32 Service API |
| Presence signal | *(none — sleep state only)* | console display state (ON always; OFF only where no suspend event exists) |
| Device presence | *(none — reopen on failure)* | `SERVICE_CONTROL_DEVICEEVENT` |
| Sleep budget | 4s, backed by a delay inhibitor | ~1.5s, and nothing can delay a suspend |
| Display / wake / arrival budget | *(n/a)* | zero — nothing is waiting, so the transport's own default applies |
| Shutdown budget | 4s, same delay inhibitor | 20s, against a 60s preshutdown timeout |
| HID transport | hidapi (hidraw backend) | hidapi (Win32 backend) |
| Logging | stdout → journal | stdout redirected to a file |
| Build system | CMake | CMake |

hidapi is cross-platform, so `HIDTransport` is unchanged on both — the only
conditional in it is a hidapi *version* guard, not a platform one. Only
`IPowerMonitor` needs a platform-specific implementation.

Logging is the one concern still handled by a conditional in `main.cpp` rather
than behind an interface. That is deliberate sequencing rather than an
oversight — see
[Planned: abstract logging](#planned-abstract-logging-behind-an-interface).

The transport seam is also what makes the CDC path viable: swapping
`HIDTransport` for `archive/SerialTransport` in `main.cpp` is the entire change
needed to support a board that cannot present as USB HID (a classic ESP32, or an
ESP8266 behind a USB-UART bridge). That transport is one-way, so its `true`
means "bytes written", not "IR fired" — a weaker guarantee, and its header says
so.

### Windows status

**Built and complete; never run as a service.** `WindowsPowerMonitor.*` was
rewritten on 2026-08-24 and finished on 2026-08-26. It builds under MSVC, and
`--console` has opened the device, sent `ON` and received the ACK on real
hardware. What has never happened is the service running — so every power event
it handles is still an unverified assumption.

The full picture, including which of the three power models each part covers, is
in [Windows — in progress](#windows--in-progress).

The `IPowerMonitor` boundary did its job: `ITransport`, `IPowerMonitor` and
`HIDTransport` carry no platform conditionals. But the original expectation of
"no changes outside `WindowsPowerMonitor`" was wrong, and stayed wrong — the
send budget became a parameter on `send()`, the transport gained `invalidate()`,
the monitor interface gained a device-presence callback, and the three power
callbacks eventually collapsed into one carrying a `TvCommand`. Everything
optional is defaulted so Linux is untouched, and the one change that was not
optional made the Linux implementation shorter rather than longer. That is the
shape the boundary was supposed to allow, and did.

### Daemon source map

```
daemon/
  CMakeLists.txt                 (build + install() rules + CPack config)
  VERSION                        (single source of the version)
  esp32-ir-remote.service.in     (unit template — CMake substitutes the bin path)
  99-esp32-ir-remote.rules       (udev rule — lets the daemon run unprivileged)
  src/
    main.cpp                     (wires transport + monitor, runs the event loop)
    ITransport.h                 (abstract: send(cmd, budget) -> bool)
    IPowerMonitor.h              (abstract: TvCommand + one command callback + run())
    HIDTransport.h / .cpp        (USB HID, sequence-correlated, budgeted)
    LinuxPowerMonitor.h / .cpp   (logind over D-Bus, inhibitor lock)
    WindowsPowerMonitor.h / .cpp (Win32 Service API — display state, device events)
    WindowsPowerCapabilities.h / .cpp
                                 (which of the three power models this machine is)
  packaging/
    postinst / prerm             (deb + rpm)
    windows/install-service.ps1  (service install, upgrade and removal)
    windows/verify-windows.ps1   (per-machine verification report)
    PKGBUILD / *.install         (Arch)
  archive/
    SerialTransport.h / .cpp     (USB CDC — not compiled, for non-HID boards)
```

| File | Notes |
|---|---|
| `VERSION` | Read by `CMakeLists.txt` and `flake.nix`. `PKGBUILD` is the one copy that must be updated by hand — makepkg needs a literal before it has fetched anything. |
| `esp32-ir-remote.service.in` | Starts after `dbus.socket` and logind. Runs unprivileged as `esp32ir` with sandboxing. CMake substitutes the binary path so the unit is correct under both `/usr/local` and `/usr`. |
| `99-esp32-ir-remote.rules` | Grants the `esp32ir` group the device's hidraw node. Without it `/dev/hidraw*` is root-only and the daemon cannot run unprivileged. |
| `HIDTransport.h/.cpp` | Drains stale reports before each write; discards replies carrying another sequence. Reopens automatically after wake or replug. Single-threaded, no background polling. |

---

## Windows — in progress

The current focus. **Written, building and complete for all three power models;
the service has never been installed.** Last worked on 2026-08-26 —
[resume here](#resume-here).

### Where it stands

| | State |
|---|---|
| Windows build | **Works.** Builds under MSVC via vcpkg, and cross-compiles clean under `-Wall -Wextra` for x86_64-w64-mingw32, linking a complete PE. |
| Device reachable | **Verified 2026-08-24.** `--console` opens the device, sends `ON`, receives the ACK, and the TV responds. |
| S3 suspend | **Written.** `PBT_APMSUSPEND` → OFF, `PBT_APMRESUMESUSPEND` → ON. Never run — the 2026-08-24 test machine has no S3 in firmware. |
| Hibernate (S4) | **Written.** Windows announces hibernate through the same `PBT_APMSUSPEND`, so it needs no separate branch; the resume side is the same two events. Never run. |
| Modern Standby | **Written.** Display state is the only signal that fires on S0ix, and it is the primary trigger for that reason. Never run as a service. |
| Power model reporting | **New 2026-08-26.** The daemon reads `SYSTEM_POWER_CAPABILITIES` at startup and logs which of the three this machine is. |
| Device arrival/removal | **New 2026-08-26.** `RegisterDeviceNotification` on the HID interface class, filtered to this VID/PID. |
| Grace-period measurement | **New 2026-08-26.** Each suspend send reports how many of its budgeted milliseconds it used. |
| USB suspend defect | **Fixed in firmware, flashed 2026-08-26, still unexercised.** Linux does not trigger the recovery path — see [below](#what-linux-actually-does-across-a-suspend). |
| Service | **Never installed.** Everything below the console check is untested. |
| Display-state design | **Unanswered.** Whether registration reports the current value — the assumption the boot `ON` rests on — needs the service running to find out. |
| Display-off scoping | **Changed 2026-08-26.** An idle screen blank asserts OFF only on a machine with no usable suspend event; the capability report decides, and the daemon logs which branch it took. Never run. |
| Per-event budgets | **Changed 2026-08-26.** The budget and the reason travel with each command, so a display change no longer inherits a suspend's 1500ms or logs itself as `(sleep)`. Never run. |

`WindowsPowerMonitor.*` was rewritten against the design in this section. It
compiles clean under `-Wall -Wextra` via an x86_64-w64-mingw32 cross-compile and
links as a complete PE with every import resolving — `CallNtPowerInformation`
from `POWRPROF.dll`, `RegisterDeviceNotificationW` and
`RegisterPowerSettingNotification` from `USER32.dll`,
`StartServiceCtrlDispatcherW` from `ADVAPI32.dll`. That is a syntax, type and
symbol check, and **not** evidence that any of it behaves correctly. Every
runtime assumption in it is still unproven.

### Three machines, not one

The 2026-08-24 plan was written around a single test machine and treated S3 as
permanently unverifiable, because that machine reports S1/S2/S3 unavailable *in
firmware*. That constraint was a property of the machine, not of the work, and
it no longer holds: there is now hardware covering all three configurations.

So the verification plan below is per-machine rather than per-feature, and the
thing that makes three days of testing on three machines add up to one record is
that each machine reports itself identically. `verify-windows.ps1` exists for
that — it reads the power model, the service configuration, the device state and
the log, and writes them in a fixed order.

**The daemon says which machine it is, in its own log.** Without that line the
rest of the log is ambiguous: an absent `PBT_APMSUSPEND` is a defect on an S3
desktop and the documented behaviour on a Modern Standby laptop, and no amount
of reading the events tells those apart.

```
[power] 14:22:31.104 machine power model: classic S3 suspend-to-RAM, hibernate available, Fast Startup on
[power] 14:22:31.104   S1=no  S2=no  S3=yes  S4=yes
[power] 14:22:31.104   hiberfil present=yes  Modern Standby (AoAc)=no
[power] 14:22:31.104   Fast Startup (Hiberboot)=yes
```

### Resume here

Ordered, because each step gates the next.

1. **Build on Windows** and run `--console` to confirm the device still answers
   after the 2026-08-26 flash. Note anything MSVC `/W4` reports — the tree is
   clean under gcc's `-Wall -Wextra`, which is not the same set.

2. **Install the service** on whichever machine is nearest, elevated, with the
   ESP32 plugged in first. The installer now prints the opening log lines when
   it finishes, which answers three things at once: which power model the machine
   is, which display-off policy that put it under, and whether display-state
   registration delivered a value.

   `display state = on` at registration means the boot `ON` works as designed.
   `no display state reported at registration` means nothing is being asserted
   and the way the opening state is read needs rethinking.

   Check the `display-off policy:` line says what the machine actually is before
   reading anything below it — it decides whether an idle screen blank is
   supposed to turn the TV off on this machine or supposed to be ignored, and
   both outcomes are a pass against the right line.

3. **Work through the verification table** on that machine, then run
   `verify-windows.ps1` and keep the report.

4. **Repeat on the other two**, so each of S3, hibernate and Modern Standby is
   covered by a machine that actually implements it.

5. **The standby cycle** remains the largest single risk, and the one thing the
   firmware fix still has not been shown to survive. Three outcomes to tell
   apart, in [the risks below](#risks-to-check-on-the-real-machine).

Not on this list and still open from before any of it: the release guard on
`v*` tags, and the registered VID/PID.

An earlier version of this brief claimed Windows was "confirmed working". That
was a typo and is not true — recorded here so the claim does not resurface.

### Where the implementation departs from the plan

Seven things came out differently once the code was written. Recorded because a
plan that silently stopped matching its implementation is worse than no plan.

| | What changed, and why |
|---|---|
| **Service detection** | The plan chose `StartServiceCtrlDispatcherW` failing with `ERROR_FAILED_SERVICE_CONTROLLER_CONNECT` as the test for "running as a service". It is the standard test and it cannot be used here: the redirect has to be decided before the first log line, and that call blocks until the service stops. A `--console` flag decides it instead; the dispatcher failure is still handled, to print guidance rather than exit silently. |
| **What `--console` does** | Not a foreground daemon — power events reach services only, so there would be nothing to listen for. It sends one `ON` and reports the ACK, which makes it a device-reachability check that needs nothing installed. The first useful thing to run after a build. |
| **Callbacks return `bool`** | `IPowerMonitor`'s callbacks were `void`. Suppressing repeat commands needs to know whether the device confirmed: recording an attempt that was never ACKed as the TV's new state would suppress the retry and leave it wrong indefinitely — the "reports success regardless" failure in a new place. Linux ignores the answer, having no such state. |
| **One callback, carrying `TvCommand`** | The three callbacks became one. Windows raises commands for six distinct triggers, only two of which are a sleep or a shutdown, and routing the other four through `OnSleep`/`OnWake` gave them the wrong deadline and the wrong name in the log. The interface lost two setters and two virtuals in the process, and `LinuxPowerMonitor` got shorter. |
| **Preshutdown timeout** | Set by the installer as the `PreshutdownTimeout` registry value, which is what `ChangeServiceConfig2` writes anyway, rather than by the service to itself at startup. It is install-time configuration and belongs with the rest of it. |
| **`GUID_CONSOLE_DISPLAY_STATE`** | Spelled out in the source rather than taken from the SDK, which declares the power-setting GUIDs but leaves their definitions in a library whose name varies by SDK version. One line, and one fewer link-time question. |
| **A third conditional in `main.cpp`** | The startup `ON` block is now inside `#ifdef __linux__`, against the stated end-state of exactly one. The honest alternative was a `justBooted()` on `IPowerMonitor` that Windows answers "never" — machinery to avoid a two-line guard. Noted rather than hidden. |

### Completing the three power models — 2026-08-26

The 2026-08-24 code already covered all three configurations behaviourally: one
display-state mechanism, with the suspend and resume events as secondary
triggers. What it could not do was tell anyone *which* configuration had
produced a given log, or notice the device it talks to coming and going. Both
matter now that the testing spans three machines.

The capability report added here for the first reason has since acquired a
second: it decides whether an idle screen blank turns the TV off on this
machine. See [the two halves of the display
signal](#the-two-halves-of-the-display-signal-are-not-equally-safe).

| Added | Why |
|---|---|
| **Power capability report at startup** | `CallNtPowerInformation(SystemPowerCapabilities)` read once and logged. Without it a log is ambiguous: an absent `PBT_APMSUSPEND` is a defect on an S3 desktop and correct on a Modern Standby laptop. |
| **Device arrival and removal** | `RegisterDeviceNotification` on the HID interface class, filtered to this VID/PID. A removal invalidates the transport's handle deliberately; an arrival re-asserts whatever state the daemon last decided the TV should be in. Deliberately *not* the last display state: on a machine where an idle blank is ignored the two disagree, and re-asserting the display would switch the TV off on a replug for a reason the policy had already rejected. Three things are tracked separately for that reason — what the screen said, what the daemon concluded, and what the TV confirmed. |
| **`PBT_APMRESUMECRITICAL`** | Resume after an unannounced power loss — an emergency hibernate on a dying battery. Deprecated and still delivered, so it is named rather than logged as an unknown event number. Treated like an automatic resume: not evidence anybody is present. |
| **Grace-period measurement** | Every suspend send reports how many of its budgeted milliseconds it used. The ~2s is guidance, not a contract, and this is the only way to learn what a given machine actually allows. |
| **Away-time reporting** | Wall-clock elapsed across a suspend, so a brief Modern Standby dip and an overnight hibernate stop looking identical in the log. |
| **Idempotent installer** | Re-running it is an upgrade: the running service is stopped and deleted, with a poll for the deletion to land, before the new one is created. An installer that only works on a clean machine stops working on the second attempt, which is exactly when it is needed. |
| **`verify-windows.ps1`** | Captures power model, service configuration, device state, selective-suspend values and the log tail into one report. What makes three sessions on three machines into one record. |

**Why the device notifications are worth the code.** They land on the path the
brief calls the largest open risk. The firmware re-enumerates itself after a USB
suspend, so a wake `ON` issued while the device is still coming back fails —
and the arrival a second later is what retries it. Without that, the TV stays
wrong until the next power event, which could be hours. The removal half is
smaller but not nothing: it makes the log say *why* the handle was dropped, on
the one path where a device vanishing and returning is routine.

Both are routed through the worker rather than acted on in the handler.
`HIDTransport` is single-threaded by design and holds no lock; the handler runs
on an SCM thread. Touching the transport from there would break the invariant
the worker exists to maintain — so the handler records and returns, exactly as
it does for power events.

**`SYSTEM_POWER_CAPABILITIES` is declared in full rather than included.** The
two fields that matter most — `AoAc`, which is how a machine says it is Modern
Standby, and `Hiberboot`, which is Fast Startup — were appended by Microsoft
into bytes the older struct reserved as spare. A current SDK declares them;
mingw-w64's `winnt.h` does not. Depending on the header would mean the capability
report existing or not according to which toolchain compiled it, and going
missing precisely on the cross-build nobody watches. The layout is documented
and stable, so it is written out once with a `static_assert` guarding against a
future SDK growing past it.

### Five decisions the sanity check reversed

Reviewing the settled decisions against each other — rather than against the
code — found places where a sound principle had been applied past where it held.
All were changed on 2026-08-26, and the reasoning is recorded where each
decision lives rather than only here.

The first three came from reading the decisions against one another. The last
two came from a second pass reading them against the
[Overview](#overview) — asking not "is this decision consistent?" but "does this
still deliver the four rows in the table this device exists for?" That is a
different question and it found different things.

| Was | Now | Why it was wrong |
|---|---|---|
| No display state at registration → **assert ON** | Assert nothing; drive from the first display-state change | "Wrong only for a restart while the display is off" *is* the 3am case the design exists to prevent, and restart-on-failure makes that a configured behaviour. See [driving from display state](#driving-from-display-state). |
| Skip any send that repeats the last asserted state | Skip only inside the suspend grace period | The optimisation was justified by the two-second window and then applied everywhere, including paths under no time pressure — discarding the drift repair that discrete IR codes exist to provide. |
| `send()` budget may only tighten the default | Honoured in both directions | It made the Linux-sized default a ceiling for every platform, capping the Windows shutdown at 4s of an available 60s — on the one send with nothing after it to correct a TV left on. |
| Display-off turns the TV off on **every** Windows machine | Only where no usable suspend event exists — see [the two halves of the display signal](#the-two-halves-of-the-display-signal-are-not-equally-safe) | One mechanism covering all three configurations was treated as the design's virtue. It is a virtue for the ON and a defect for the OFF: it took a behaviour a Modern Standby laptop forces — the TV going off under somebody still watching — and applied it to an S3 desktop that had a better signal available and needed nothing. |
| Sleep and shutdown budgets supplied by `IPowerMonitor::sleepBudget()` / `shutdownBudget()` | The budget and the reason travel with the command, as `TvCommand` | The budget was attached to an event *class* rather than to the event. Once Windows drove the TV from display state, a screen blanking was routed through the sleep callback and inherited a suspend's 1500ms — on a path where nothing was waiting for the daemon at all, and which is among the likeliest to find the ESP32 mid-re-enumeration. It logged itself as `(sleep)` too. |

The pattern in all five is the same, and it is the one the
[History](#history) section already names: a fix that closed the case in front
of it without closing the class it belonged to. Each was a correct decision
about one path, generalised one step too far.

The fifth is worth separating from the other four, because it is not only a
wrong decision but a *shape* that produces them. Three callbacks that each
implied their own deadline meant the deadline could not be stated per event;
anything routed through the sleep callback silently became a sleep. Collapsing
them to one callback carrying `{on, reason, budget}` removes the category, which
is the difference between fixing the instance and closing the class.

**Event Log is still deliberately not done.** It is the idiomatic Windows
answer and it stays on the list rather than in the code, for the reason already
recorded under [Logging](#logging--decided): it needs a registered event source,
a message resource DLL, and a logging abstraction spanning both platforms, and
its benefits accrue to administrators managing machines they did not build.
That is still not the situation. Get the three power models verified first.

### What needs no work at all

The transport layer is genuinely shared. `ITransport`, `IPowerMonitor` and
`HIDTransport` contain **zero** platform conditionals, hidapi covers the Win32
HID backend, and `CMakeLists.txt` already resolves it through vcpkg. That was
the point of the abstraction and it held.

The firmware needs nothing either. Its report descriptor declares a
vendor-defined usage page (`0xFF00`), so Windows binds `hidclass` automatically:
no driver to write, no INF to sign, and none of the access restrictions Windows
places on keyboard and mouse top-level collections.

### The architectural difference — accepted, not solved

Windows has no equivalent of a logind delay inhibitor for **sleep**. The ability
to veto a suspend (`PBT_APMQUERYSUSPEND`) was removed after XP.
`PBT_APMSUSPEND` is a *notification*: the machine suspends roughly two seconds
later whether anything has finished or not. That figure is Microsoft's guidance,
not a contract — measure it on real hardware before trusting it.

| Event | Linux | Windows |
|---|---|---|
| Sleep | delay inhibitor, 5s guaranteed | ~2s grace, **best-effort** |
| Wake | no guarantee needed — machine is up | same |
| Shutdown | delay inhibitor, 5s | `SERVICE_ACCEPT_PRESHUTDOWN`, minutes — **better than Linux** |
| Boot | no guarantee needed | same |

Only sleep degrades, and only from "guaranteed" to "almost always". The measured
IR round trip is well under a second, so the grace period is ample in the healthy
case. This is a documented concession, not a bug to fix.

The ACK still matters on Windows sleep even though nothing can be done with it:
it is the only evidence the IR actually fired, on the platform with no console.
Dropping to fire-and-forget would reintroduce exactly the "reports success
regardless" failure that fixes 1, 12, 13 and 21 all addressed.

### Windows is three configurations, not one

Windows varies along two independent axes, and the combinations are not edge
cases. This plan originally targeted the rarest of them.

**Boot.** Fast Startup — on by default wherever hibernation is enabled — makes
"shut down" a hibernation of the kernel session rather than a true shutdown. The
tick count does not reset across it. That is why Task Manager reports multi-day
uptime on a machine that gets shut down every night.

**Sleep.** A machine supports either classic S3 suspend or Modern Standby (S0
low power idle). It is a property of the platform firmware: never both, and not
switchable.

| Configuration | Boot ON | Sleep OFF |
|---|---|---|
| S3, Fast Startup off | uptime gate works | `PBT_APMSUSPEND`, ~2s grace |
| S3, Fast Startup on | **uptime gate never fires** | `PBT_APMSUSPEND`, ~2s grace |
| Modern Standby | **uptime gate never fires** | no classic suspend — `PBT_APMSUSPEND` may not arrive usefully at all |

Porting `systemJustBooted()` with `GetTickCount64()` is the obvious translation
and it is correct only in the first row. In the other two the machine powers on
carrying a tick count of hours, the gate skips, and the daemon logs `ON skipped
— service restarted on an already-running system, not a boot`. That is worse
than a missed command: it is a wrong reason recorded in the log, for the one
feature the device exists to provide.

It compounds. On a Fast Startup power-on the kernel resume completes before the
SCM starts services, so the daemon registers its control handler too late to
catch a resume broadcast either. Both routes to "TV on when the PC turns on"
close at the same time.

Modern Standby is the other half. Machines using S0 low-power idle never enter
S3, the power-event model differs, and the plan had a *check* for it
(`powercfg /a`) but no design for the branch where the check comes back S0.
A product cannot ship a sleep path that only works on one of two power models.

### Driving from display state

`RegisterPowerSettingNotification` on `GUID_CONSOLE_DISPLAY_STATE`, with
`DEVICE_NOTIFY_SERVICE_HANDLE`. Notifications arrive through the service control
handler that already exists, as `SERVICE_CONTROL_POWEREVENT` carrying
`dwEventType = PBT_POWERSETTINGCHANGE`.

What each source can answer, before any decision about which to use:

| Question | Suspend/resume events | Display state |
|---|---|---|
| Boot ON under Fast Startup | never fires | registration delivers the current value — display on at boot → ON |
| Unattended 3am wake | `PBT_APMRESUMEAUTOMATIC` turns the TV on | display stays off on a maintenance wake → nothing fires |
| Modern Standby sleep | no design | this *is* the documented S0ix signal |
| S3 sleep | `PBT_APMSUSPEND`, works | *could* work — the display goes off ahead of the suspend — but it also fires on an idle blank that is not a suspend at all, which is why it is not used here |

Only the last row is a choice rather than a constraint, and it is the one the
subsection below is about.

**Why being liberal about triggers is safe.** The IR codes are discrete, not
toggle — see [Manufacturer profiles](#manufacturer-profiles), where that choice
was made so the TV reaches the right state regardless of prior drift. The
consequence here is that re-asserting a state the TV is already in is a no-op at
the TV. So display state and `PBT_APMSUSPEND` can both be handled without either
having to be exactly right; whichever arrives first wins and the other is
absorbed.

#### The two halves of the display signal are not equally safe

This section originally read "one mechanism covers all three configurations",
and treated that as the design's chief virtue. It is a virtue for the ON and a
defect for the OFF, and collapsing them cost something real.

**Display on → ON, on every machine.** The screen lighting up answers "is
anyone there?" as directly as any Windows API does, and the failure mode if it
is wrong is a TV switched on that the user turns off with their own remote. It
is also the only route to an ON at boot, because the uptime gate does not
survive Fast Startup. Nothing about this is machine-specific.

**Display off → OFF, only where nothing else can.** Here the failure mode is the
opposite shape and much worse: the TV switches off under somebody who is still
watching. The mitigation is an assumption about other people's software —
players are supposed to assert `ES_DISPLAY_REQUIRED` and the good ones do, but
browsers and games are less consistent, and a game played on a controller
generates no keyboard or mouse input at all. A PC connected to a television is
this device's whole use case, so that failure lands exactly where it hurts most.

On a **Modern Standby** machine that cost has to be paid: there is no classic
suspend, `PBT_APMSUSPEND` may never arrive usefully, and a TV that never
switches off fails one of the four rows in the [Overview](#overview) table. On a
machine that reports **classic S3**, it does not: `PBT_APMSUSPEND` arrives, says
what it means, and is the honest cause. Taking the behaviour a Modern Standby
laptop forces and applying it to an S3 desktop buys nothing and pays the full
price.

So the policy is per machine, decided from the capability report the daemon
already reads at startup:

| Machine reports | Display off | What drives the OFF |
|---|---|---|
| S3, not Modern Standby | ignored | `PBT_APMSUSPEND` |
| Modern Standby (`AoAc`) | **asserts OFF** | display state — the only signal there is |
| Neither, or capabilities unreadable | **asserts OFF** | display state, because no suspend event can be relied on |

The third row is the permissive one and is deliberate. "Unknown" means nothing
can be assumed about whether a suspend event will ever arrive, and between a TV
that occasionally switches off early and a TV that never switches off at all,
the first is the annoyance and the second is a broken product.

`displayOffDrivesOff()` in `WindowsPowerMonitor.cpp` is that table, and the
daemon logs which branch it took on the line after the capability report — so a
missing OFF on a screen blank reads as the documented behaviour rather than as a
defect, without anybody having to remember which machine the log came from.

**What this changes about the capability report.** It was added on 2026-08-26 as
pure diagnostics — a line so a log could not be filed against the wrong
configuration. It is now load-bearing: `AoAc` decides a behaviour. That is worth
stating because it changes what a wrong reading costs. A machine that
misreports, or one where `CallNtPowerInformation` fails, no longer merely
produces a confusing log; it runs the wrong policy. The failure is bounded in
the direction that matters — the fallback is the permissive branch, which errs
towards the device doing its job — but it is no longer free.

**This is the same mistake the [reversals](#five-decisions-the-sanity-check-reversed)
section is about**, committed one more time in the section that records them: a
decision that was correct for one machine, generalised to every machine because
the mechanism happened to be available everywhere. It is listed as the fourth
reversal there.

**Suppressing the duplicate is scoped to the suspend path, and only there.**
The last asserted state is tracked, but a send that would repeat it is skipped
*only* inside a suspend — the one place under time pressure, where two IR
transmissions would not fit comfortably in the two-second grace period.

Everywhere else the repeat is sent. This was originally applied everywhere, and
that was wrong for a reason worth stating: it argues directly against the
sentence above it. Discrete codes were chosen so the TV reaches the right state
*regardless of prior drift*, and drift is exactly what happens when somebody
picks up the TV's own remote. Re-asserting a state the TV is already in is a
no-op; re-asserting one it has drifted out of is the repair. Skipping the send
outside a suspend throws the repair away to save time nothing is asking for.

The same reasoning governs what the daemon is entitled to remember. A device
removal resets the last asserted state to unknown, because while the ESP32 is
unplugged there is no channel to the TV at all — and somebody unplugging it is
a fairly good indicator that they are about to use the TV another way.

**What disappears.** `systemJustBooted()` never gains a Windows branch. The
question "was this a boot or a `sc restart`?" exists on Linux only because a
restart would assert ON with nobody at the machine — see the comment at the top
of `systemJustBooted()`. Display state answers presence directly, so the
question dissolves rather than needing an answer harder than `/proc/uptime`.

**Why not resume events alone.** `PBT_APMRESUMEAUTOMATIC` is documented as
firing on every resume *and* as explicitly not implying the user is present:
wake timers, maintenance windows and update-driven wakes all raise it. Handling
it alone therefore reintroduces, by a different route, the exact defect the
uptime gate was written to remove — a daemon turning the TV on at 3am with
nobody there. Handling only `PBT_APMRESUMESUSPEND`, as the code does today,
fails the opposite way and leaves the TV off for Wake-on-LAN. The two events are
a *presence discriminator*; choosing one throws away the information. They also
cannot be collapsed at the point of arrival, because AUTOMATIC comes first and
whether RESUMESUSPEND follows is not yet known.

**The behaviour this changes, and how much of a choice it really was.**
On a Modern Standby machine, display-off on an idle timeout turns the TV off
while the user is still sitting there. That should be recorded honestly as a
decision the API made rather than one the product did: Modern Standby exposes no
usable suspend event, so display state is not the best available signal on that
machine, it is the only one. The product behaviour was chosen to fit the
mechanism, and scoping it to that machine is as far as the constraint can be
pushed back.

Two things remain worth being straight about, both now narrower than they were:

- **Windows and Linux are still different products, on one class of machine.**
  Linux drives from sleep state only and never watches the display. An S3
  Windows machine now matches it. A Modern Standby laptop does not, and cannot
  without an idle signal Windows does not offer to a session-0 service in any
  other form. That residue is forced rather than chosen, which makes it
  something to document for users rather than a decision still owed. The
  alternative — teaching Linux the same trick via a session idle or DPMS signal
  — would spread a behaviour nobody wants to a platform that has no need of it,
  and is not planned.
- **The mitigation is an assumption about other people's software.** Media
  players are supposed to assert `ES_DISPLAY_REQUIRED` so the screen does not
  blank during playback, and the good ones do. Browsers and games are less
  consistent, and a game played on a controller produces no keyboard or mouse
  input at all. The failure is loud: the TV switches off part-way through
  whatever is being watched. Worth testing deliberately with a browser-based
  player and with a controller game on the Modern Standby machine — it is the
  most likely source of a "this thing is broken" report from an actual user, and
  it is now the *only* configuration where it can happen.

**Two things to confirm before committing to this**, since the boot ON depends
entirely on the first:

- that registration delivers the current display state immediately, rather than
  only on the next change;
- that `GUID_CONSOLE_DISPLAY_STATE` reaches a session-0 service as documented —
  `GUID_SESSION_DISPLAY_STATUS` is the per-session equivalent for user
  applications, and the two are easy to confuse.

**If the first turns out to be false, the fallback asserts nothing.** The
opening state stays unknown and the TV is driven from the first display-state
*change* instead.

This was originally "assert ON at service start unconditionally, which is wrong
only for a restart that happens while the display is off". That dismissal does
not survive being read next to the rest of this section. A restart while the
display is off *is* the 3am case — the one the uptime gate exists to prevent on
Linux and the one `PBT_APMRESUMEAUTOMATIC` is deliberately ignored to avoid here
— and the installer configures `restart/5000` on failure, which makes an
unattended restart a configured behaviour rather than a hypothetical. The
fallback would also be most active on precisely the machine where registration
does not deliver, so it was riskiest where it was most likely to run.

The asymmetry stated further down settles it: a spurious OFF is corrected by the
next display-on notification, while a spurious ON leaves a lit TV in a dark room
until somebody notices. A missed ON the user can undo with their own remote is
the smaller failure.

The cost is real and is not hidden: on a machine where the initial value never
arrives, nothing drives the TV until the first display transition. Reaching that
line at all means the assumption this whole design rests on is false on that
machine, so it is logged as a diagnostic — three lines saying the opening state
is unknown and that the boot `ON` needs rethinking — rather than quietly papered
over with a guess.
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

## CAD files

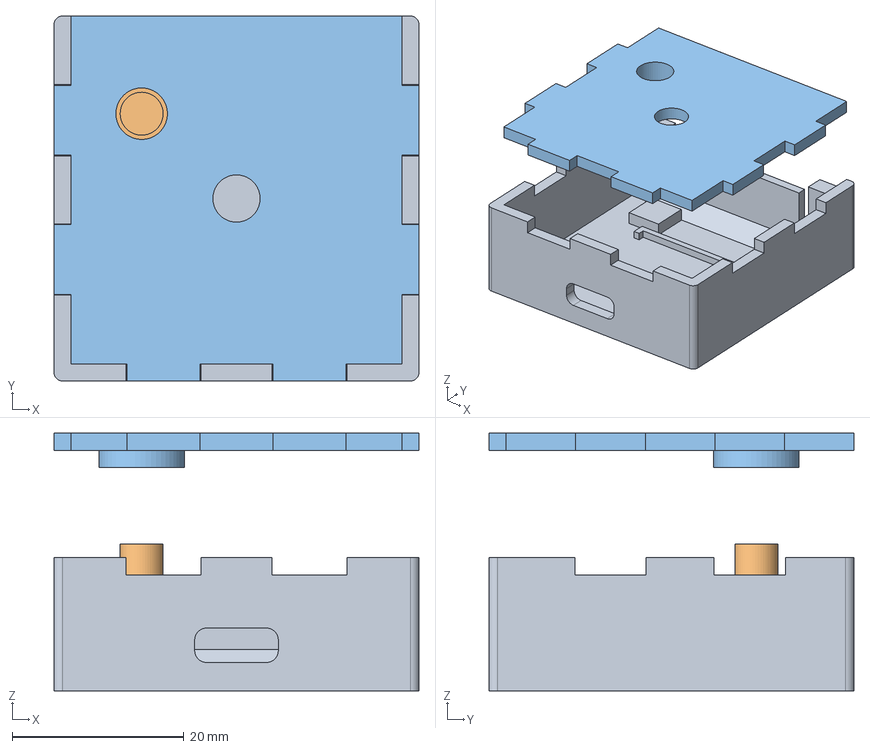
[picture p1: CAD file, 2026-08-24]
hardware/ESP32-Remote-Housing.FCStd
42.5 x 42.5 x 30.0 mm
Housing Bottom
Button Pusher
Housing Top

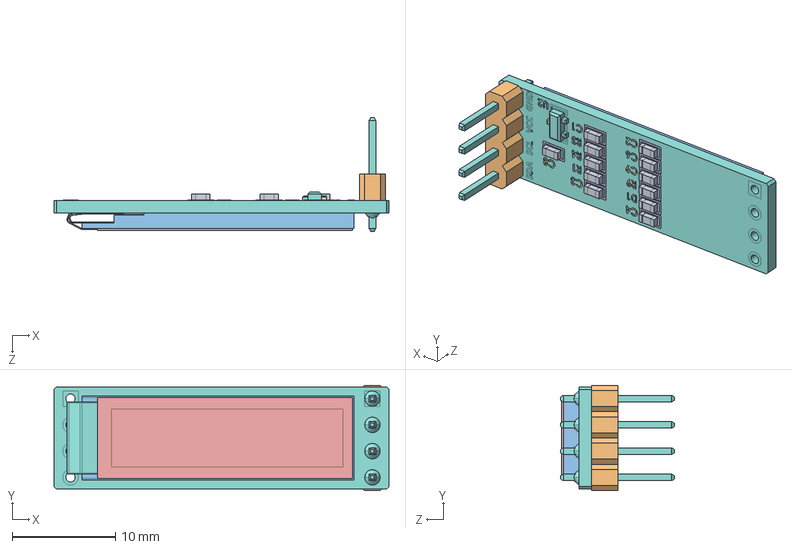
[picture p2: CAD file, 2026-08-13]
hardware/TFT-Display-0.69_96x16.STEP
32.4 x 10.2 x 11.0 mm

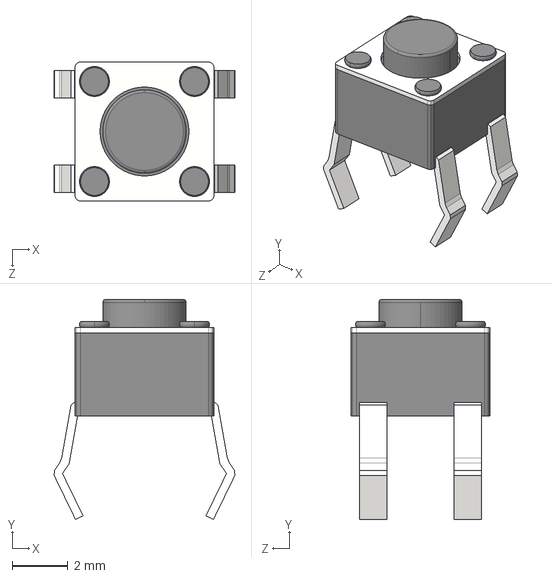
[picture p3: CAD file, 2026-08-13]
hardware/Push_Button.STEP
6.50 x 7.92 x 5.00 mm
Button_top
Button_leg x 4

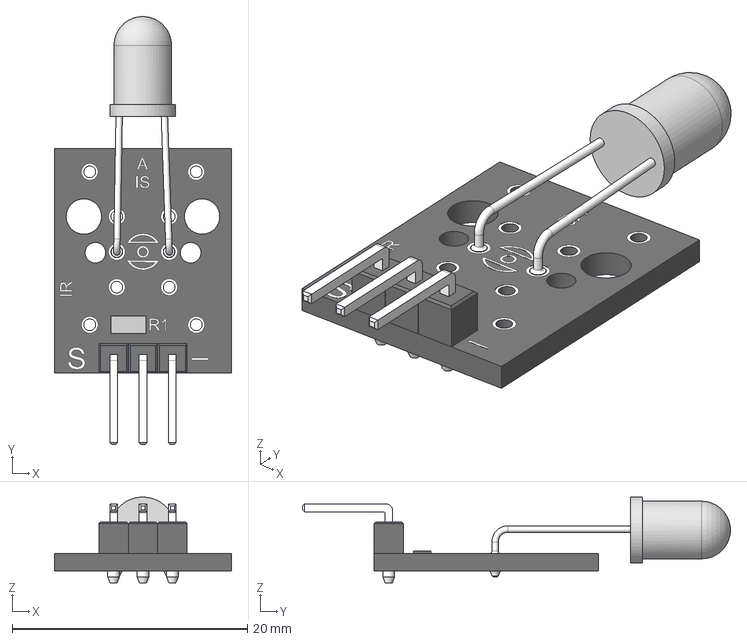
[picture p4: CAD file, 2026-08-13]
hardware/KY-005-transmitter-v1.step
15.1 x 36.4 x 7.30 mm

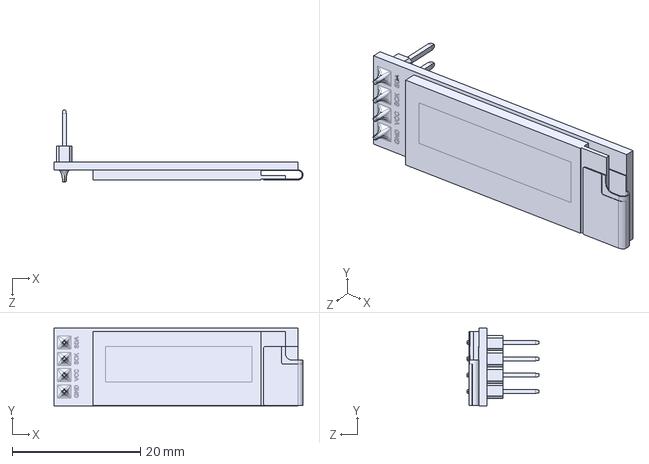
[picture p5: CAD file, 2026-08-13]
hardware/0.91in-OLED.STEP
38.8 x 12.1 x 11.2 mm

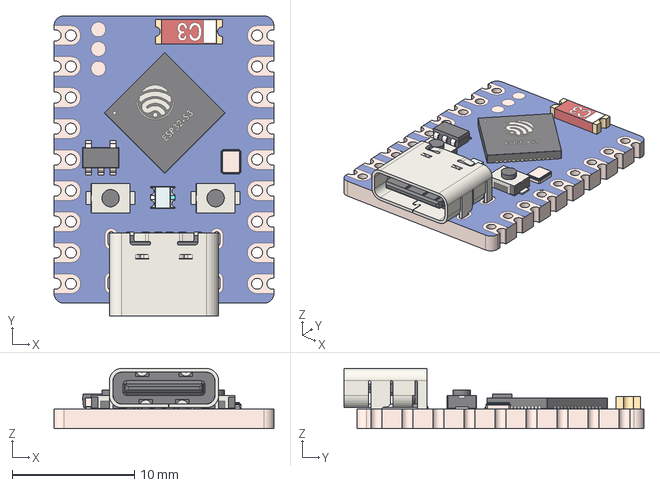
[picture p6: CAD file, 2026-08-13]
hardware/ESP32-S3_Zero.step
18.0 x 24.6 x 4.92 mm

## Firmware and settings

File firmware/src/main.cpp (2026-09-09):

#include <Arduino.h>
#include <Wire.h>
#include <Adafruit_GFX.h>
#include <Adafruit_SSD1306.h>
#include <IRremoteESP8266.h>
#include <IRsend.h>
#include <WiFi.h>
#include <WebServer.h>
#include <LittleFS.h>
#include <ArduinoJson.h>
#include "USB.h"
#include "USBHID.h"
#include "esp_task_wdt.h"

#include "tusb.h"
#include "Profiles.h"
#include "Button.h"
#include "Display.h"

#define IR_TX_PIN    4
#define OLED_SDA     2
#define OLED_SCL     3
#define BUTTON_PIN   5

#define OLED_WIDTH  128
#define OLED_HEIGHT  32
#define OLED_ADDR   0x3C

#define DEVICE_VID  0x1209
#define DEVICE_PID  0x0001
#define REPORT_SIZE    64

#define WIFI_SSID  "ESP32-IR-Remote"
#define WIFI_PASS  "irremote123"

// Hardware watchdog. Reboots the device if loop() ever stops running.
//
// This is the one failure the device has no other defence against: nothing on
// the PC side can tell a hung stick from an unplugged one, so a hang would
// persist until somebody noticed the TV had stopped following the PC. A reset
// is a clean recovery — profiles live in flash and the daemon reopens the
// device on its next send.
//
// 20s is sized by the web server, not by anything in our own code. Serving the
// config page can legitimately block for around 12s inside a single loop()
// iteration if a client stalls: WebServer waits up to 5s for the request, 5s
// for data to be ACKed and 2s for the close. Everything else in loop() —
// button, display, IR, HID — is under 200ms. The margin matters more than fast
// detection here, because a false reset while somebody is saving IR codes over
// the web UI would be worse than a slow one.
#define WDT_TIMEOUT_SECONDS 20

static const uint8_t REPORT_DESCRIPTOR[] = {
    0x06, 0x00, 0xFF,
    0x09, 0x01,
    0xA1, 0x01,
    0x09, 0x01,
    0x15, 0x00,
    0x26, 0xFF, 0x00,
    0x75, 0x08,
    0x95, REPORT_SIZE,
    0x81, 0x02,
    0x09, 0x02,
    0x15, 0x00,
    0x26, 0xFF, 0x00,
    0x75, 0x08,
    0x95, REPORT_SIZE,
    0x91, 0x02,
    0xC0
};

Adafruit_SSD1306 oled(OLED_WIDTH, OLED_HEIGHT, &Wire, -1);
IRsend           irSend(IR_TX_PIN);
USBHID           HID;
Button           button(BUTTON_PIN);
Display          display(oled);
WebServer        server(80);

bool    wifiActive = false;

uint8_t pressCount = 0;

class VendorHID : public USBHIDDevice {
public:
    VendorHID() {}

    void begin() { HID.addDevice(this, sizeof(REPORT_DESCRIPTOR)); }

    uint16_t _onGetDescriptor(uint8_t* dst) override {
        memcpy(dst, REPORT_DESCRIPTOR, sizeof(REPORT_DESCRIPTOR));
        return sizeof(REPORT_DESCRIPTOR);
    }

    void _onOutput(uint8_t report_id, const uint8_t* buffer, uint16_t len) override {

        if (len < 2) return;

        uint16_t copyLen = min((int)len, REPORT_SIZE - 1);
        memcpy(rxBuf_, buffer, copyLen);
        rxBuf_[copyLen] = '\0';
        received_ = true;
    }

    bool send(const uint8_t* data) {
        return HID.SendReport(0, data, REPORT_SIZE);
    }

    volatile bool received_     = false;
    uint8_t rxBuf_[REPORT_SIZE] = {0};
};

VendorHID hidDevice;

volatile bool usbResumePending = false;
volatile bool usbWasSuspended  = false;

static void onUsbEvent(void* , esp_event_base_t ,
                       int32_t id, void* ) {
    switch (id) {
    case ARDUINO_USB_SUSPEND_EVENT:
        usbWasSuspended = true;
        break;
    case ARDUINO_USB_RESUME_EVENT:

        if (usbWasSuspended) {
            usbWasSuspended  = false;
            usbResumePending = true;
        }
        break;
    default:
        break;
    }
}

static void serviceUsbRecovery() {
    if (!usbResumePending) return;
    usbResumePending = false;

    Serial.println("[usb] Resumed from suspend — re-enumerating");

    tud_disconnect();
    delay(100);
    tud_connect();
}

bool sendIR(const Profile& profile, bool on) {
    if (!Profiles::isConfigured(profile, on)) {
        Serial.printf("[ir] %s has no %s code configured — not transmitting\n",
                      profile.name.c_str(), on ? "ON" : "OFF");
        return false;
    }

    uint32_t code = on ? profile.onCode : profile.offCode;
    switch (profile.protocol) {
        case IrProtocol::SAMSUNG:
            irSend.sendSAMSUNG(code, kSamsungBits);
            break;
        case IrProtocol::SONY:
            // 12 bits, not 20. SIRC has three lengths, and a TV is category 1,
            // which is the 12-bit form — at 20 bits the same command becomes a
            // different waveform and the TV does not answer.
            irSend.sendSony(code, kSony12Bits);
            break;
        case IrProtocol::NEC:
        default:
            irSend.sendNEC(code, kNECBits);
            break;
    }
    return true;
}

void stopWifi();

void startWifi() {
    WiFi.mode(WIFI_AP);
    WiFi.softAP(WIFI_SSID, WIFI_PASS);
    String apIP = WiFi.softAPIP().toString();
    Serial.printf("[wifi] AP started — SSID: %s  IP: %s\n", WIFI_SSID, apIP.c_str());
    display.setWifiIP(apIP);

    server.on("/api/profiles", HTTP_GET, []() {
        JsonDocument doc;
        JsonArray arr = doc.to<JsonArray>();

        for (const auto& p : Profiles::getAll()) {
            Profiles::toJson(p, arr.add<JsonObject>());
        }
        String json;
        serializeJson(doc, json);
        server.send(200, "application/json", json);
    });

    server.on("/api/profiles", HTTP_POST, []() {
        JsonDocument doc;
        DeserializationError err = deserializeJson(doc, server.arg("plain"));
        if (err) {
            server.send(400, "application/json", "{\"error\":\"Invalid JSON\"}");
            return;
        }

        std::vector<Profile> newProfiles;
        for (JsonObjectConst obj : doc.as<JsonArrayConst>()) {
            newProfiles.push_back(Profiles::fromJson(obj));
        }
        if (newProfiles.empty()) {
            server.send(400, "application/json", "{\"error\":\"At least one profile required\"}");
            return;
        }
        if (newProfiles.size() > Profiles::MAX_PROFILES) {
            server.send(400, "application/json",
                        "{\"error\":\"Too many profiles\"}");
            return;
        }
        Profiles::replaceAll(std::move(newProfiles));
        Profiles::saveProfiles();
        Profiles::saveSettings();
        display.showStatus(Profiles::getActive().name, true);
        server.send(200, "application/json", "{\"ok\":true}");
    });

    server.on("/api/settings", HTTP_GET, []() {
        const Settings& s = Profiles::getSettings();
        JsonDocument doc;
        doc["active_profile"]    = s.activeProfile;
        doc["display_always_on"] = s.displayAlwaysOn;
        String json;
        serializeJson(doc, json);
        server.send(200, "application/json", json);
    });

    server.on("/api/settings", HTTP_POST, []() {
        JsonDocument doc;
        DeserializationError err = deserializeJson(doc, server.arg("plain"));
        if (err) {
            server.send(400, "application/json", "{\"error\":\"Invalid JSON\"}");
            return;
        }

        Settings& s = Profiles::getMutableSettings();
        if (doc["active_profile"].is<int>()) {
            int idx = doc["active_profile"].as<int>();
            if (idx >= 0 && idx < (int)Profiles::getAll().size()) {
                s.activeProfile = idx;
            }
        }
        if (doc["display_always_on"].is<bool>()) {
            s.displayAlwaysOn = doc["display_always_on"].as<bool>();
        }
        Profiles::saveSettings();
        display.showStatus(Profiles::getActive().name, true);
        server.send(200, "application/json", "{\"ok\":true}");
    });

    server.on("/api/factory-reset", HTTP_POST, []() {
        Profiles::factoryReset();
        server.send(200, "application/json", "{\"ok\":true}");
        wifiActive = false;
    });

    server.on("/api/exit", HTTP_POST, []() {
        server.send(200, "application/json", "{\"ok\":true}");

        wifiActive = false;
    });

    server.onNotFound([]() {
        String path = server.uri();
        if (path == "/") path = "/index.html";

        if (LittleFS.exists(path)) {
            String contentType = "text/plain";
            if      (path.endsWith(".html")) contentType = "text/html";
            else if (path.endsWith(".css"))  contentType = "text/css";
            else if (path.endsWith(".js"))   contentType = "application/javascript";
            else if (path.endsWith(".json")) contentType = "application/json";

            File f = LittleFS.open(path, "r");
            server.streamFile(f, contentType);
            f.close();
        } else {
            server.send(404, "text/plain", "Not Found");
        }
    });

    server.begin();
    Serial.println("[wifi] Web server started on port 80");
}

void stopWifi() {
    server.stop();
    WiFi.softAPdisconnect(true);
    WiFi.mode(WIFI_OFF);
    Serial.println("[wifi] AP stopped");
}

void finishExitWifi() {
    if (WiFi.getMode() != WIFI_OFF) stopWifi();
    wifiActive = false;
    display.setWifiActive(false);
    display.showStatus(Profiles::getActive().name,
                       Profiles::getSettings().displayAlwaysOn);
    pressCount = 1;
}

void onButtonPress() {
    pressCount++;
    bool alwaysOn = Profiles::getSettings().displayAlwaysOn || wifiActive;

    if (wifiActive) {
        if (pressCount == 1) {

            display.showStatus(Profiles::getActive().name, true);
        } else {

            display.showWifiLockMessage();
            pressCount = 1;
        }
        return;
    }

    if (pressCount == 1) {

        display.showStatus(Profiles::getActive().name, alwaysOn);
    } else {

        int next = Profiles::nextVisibleIndex();
        Profiles::getMutableSettings().activeProfile = next;
        Profiles::saveSettings();

        display.showStatus(Profiles::getActive().name, alwaysOn);
        pressCount = 1;
    }
}

void onButtonHold(uint32_t heldMs) {

    pressCount = 0;

    if (heldMs >= HoldTimings::RESET_END_MS) {

        return;
    } else if (heldMs >= HoldTimings::RESET_START_MS) {
        display.showResetBar(heldMs);
    } else if (heldMs >= HoldTimings::CONFIG_MS) {
        display.showConfigRelease(!wifiActive);
    } else {
        display.showHoldBar(heldMs, !wifiActive);
    }
}

void onConfigThreshold() {

    if (wifiActive) {
        finishExitWifi();
    } else {
        wifiActive = true;
        display.setWifiActive(true);
        startWifi();

        display.showStatus(Profiles::getActive().name, true);
        pressCount = 1;
    }
}

void onFactoryReset() {
    Serial.println("[app] Factory reset triggered");
    Profiles::factoryReset();
    finishExitWifi();
}

void setup() {
    Serial.begin(115200);

    if (!Profiles::begin()) {
        Serial.println("[app] Profile storage unavailable — using fallback profile");
    }

    Wire.begin(OLED_SDA, OLED_SCL);
    if (oled.begin(SSD1306_SWITCHCAPVCC, OLED_ADDR)) {
        display.begin();
    }

    button.begin();
    button.onPress           = onButtonPress;
    button.onHold            = onButtonHold;
    button.onHoldCancelled   = []() {

        bool alwaysOn = Profiles::getSettings().displayAlwaysOn || wifiActive;
        display.showStatus(Profiles::getActive().name, alwaysOn);
        pressCount = 1;
    };
    button.onConfigThreshold = onConfigThreshold;
    button.onFactoryReset    = onFactoryReset;

    display.onExpire = []() { pressCount = 0; };

    display.showStatus(Profiles::getActive().name,
                       Profiles::getSettings().displayAlwaysOn);

    irSend.begin();

    hidDevice.begin();
    USB.VID(DEVICE_VID);
    USB.PID(DEVICE_PID);
    USB.productName("ESP32 IR Remote");
    USB.manufacturerName("ESP32-IR-CEC");

    USB.onEvent(ARDUINO_USB_SUSPEND_EVENT, onUsbEvent);
    USB.onEvent(ARDUINO_USB_RESUME_EVENT, onUsbEvent);

    USB.begin();
    HID.begin();

    // Started last, so setup() itself is never watched. A hang before this
    // point is a bricked-at-boot device, which you find the moment you flash
    // it; the watchdog is here for the silent hang months later. It also keeps
    // first-boot LittleFS formatting from having to fit inside the timeout.
    esp_task_wdt_init(WDT_TIMEOUT_SECONDS, true);
    esp_task_wdt_add(NULL);
    Serial.printf("[wdt] Watchdog armed (%ds)\n", WDT_TIMEOUT_SECONDS);
}

void loop() {
    esp_task_wdt_reset();

    button.update();
    display.update();

    serviceUsbRecovery();

    if (wifiActive) {
        server.handleClient();
    } else if (WiFi.getMode() != WIFI_OFF) {

        finishExitWifi();
    }

    if (!hidDevice.received_) return;
    hidDevice.received_ = false;

    const uint8_t seq = hidDevice.rxBuf_[0];

    String cmd = String((char*)hidDevice.rxBuf_ + 1);
    cmd.trim();

    const bool alwaysOn = Profiles::getSettings().displayAlwaysOn || wifiActive;
    const Profile& active = Profiles::getActive();

    uint8_t response[REPORT_SIZE] = {0};
    response[0] = seq;

    bool ok = false;
    if (cmd == "ON" || cmd == "OFF") {
        const bool on = (cmd == "ON");
        ok = sendIR(active, on);
        if (ok) {
            display.showIRConfirm(on, alwaysOn, active.name);
        } else {
            display.showNotConfigured(alwaysOn, active.name);
        }
    }

    memcpy(response + 1, ok ? "ACK" : "ERR", 3);

    if (!hidDevice.send(response)) {

        Serial.println("[hid] Failed to queue response report");
    }
}

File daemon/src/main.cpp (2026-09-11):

#include "IPowerMonitor.h"
#include "ITransport.h"
#include "HIDTransport.h"

#ifdef __linux__
#include "LinuxPowerMonitor.h"
#elif defined(_WIN32)
#include "WindowsPowerMonitor.h"
#include <windows.h>
#include <cstdio>
#include <string>
#endif

#include <fstream>
#include <iostream>
#include <memory>
#include <stdexcept>

static constexpr uint16_t DEVICE_VID = 0x1209;
static constexpr uint16_t DEVICE_PID = 0x0001;

#ifdef __linux__

static constexpr double BOOT_WINDOW_SECONDS = 180.0;

// Guards the boot ON against a package upgrade restarting the service at 3am.
static bool systemJustBooted() {
    std::ifstream uptimeFile("/proc/uptime");
    double uptimeSeconds = 0.0;
    if (uptimeFile >> uptimeSeconds) {
        return uptimeSeconds < BOOT_WINDOW_SECONDS;
    }

    return true;
}

#endif

#ifdef _WIN32

static bool consoleMode() {
    const wchar_t* cmdline = GetCommandLineW();
    return cmdline && wcsstr(cmdline, L"--console") != nullptr;
}

static HANDLE g_singleInstance = nullptr;

static bool claimSingleInstance() {
    g_singleInstance = CreateMutexW(nullptr, TRUE, L"Global\\ESP32IRRemote_SingleInstance");
    const DWORD err = GetLastError();

    if (g_singleInstance && err != ERROR_ALREADY_EXISTS) return true;

    if (g_singleInstance) {
        CloseHandle(g_singleInstance);
        g_singleInstance = nullptr;
    }
    return false;
}

static std::wstring logDirectory() {
    wchar_t env[MAX_PATH] = {0};
    const DWORD len = GetEnvironmentVariableW(L"ProgramData", env, MAX_PATH);
    if (len > 0 && len < MAX_PATH) {
        return std::wstring(env) + L"\\ESP32IRRemote";
    }
    return L"C:\\ProgramData\\ESP32IRRemote";
}

static void redirectLogsToFile() {
    const std::wstring dir  = logDirectory();
    CreateDirectoryW(dir.c_str(), nullptr);

    const std::wstring path = dir + L"\\daemon.log";
    const std::wstring prev = dir + L"\\daemon.log.old";

    WIN32_FILE_ATTRIBUTE_DATA info = {};
    if (GetFileAttributesExW(path.c_str(), GetFileExInfoStandard, &info)) {
        const ULONGLONG size =
            (static_cast<ULONGLONG>(info.nFileSizeHigh) << 32) | info.nFileSizeLow;
        if (size > 1024ULL * 1024ULL) {
            MoveFileExW(path.c_str(), prev.c_str(), MOVEFILE_REPLACE_EXISTING);
        }
    }

    FILE* out = nullptr;
    FILE* err = nullptr;
    _wfreopen_s(&out, path.c_str(), L"a", stdout);
    _wfreopen_s(&err, path.c_str(), L"a", stderr);
}

#endif

int main() {

    std::cout << std::unitbuf;

#ifdef _WIN32

    const bool console = consoleMode();
    if (console) {

        SetConsoleOutputCP(CP_UTF8);
    } else {
        redirectLogsToFile();
    }

    if (!claimSingleInstance()) {
        std::cerr << "[error] Another instance is already running — refusing to start.\n"
                     "[error] Stop the esp32-ir-remote service before running by hand;\n"
                     "[error] two openers of the same HID device steal each other's ACKs.\n";
        return 1;
    }
#endif

    std::unique_ptr<ITransport> transport;
    try {
        transport = std::make_unique<HIDTransport>(DEVICE_VID, DEVICE_PID);
    } catch (const std::exception& e) {
        std::cerr << "[error] " << e.what() << "\n";
        return 1;
    }

    std::unique_ptr<IPowerMonitor> monitor;

#ifdef __linux__
    try {
        monitor = std::make_unique<LinuxPowerMonitor>(DEVICE_VID, DEVICE_PID);
        std::cout << "[monitor] Connected to systemd-logind\n";
    } catch (const std::exception& e) {
        std::cerr << "[error] Failed to connect to D-Bus: " << e.what() << "\n";
        return 1;
    }
#elif defined(_WIN32)
    monitor = std::make_unique<WindowsPowerMonitor>(DEVICE_VID, DEVICE_PID);
    std::cout << "[monitor] Windows Service power monitor initialised\n";
#else
    std::cerr << "[error] No power monitor available for this platform\n";
    return 1;
#endif

    auto report = [](const char* cmd, const char* reason, bool ok) {
        if (ok) {
            std::cout << "[cmd] " << cmd << " sent and ACK received (" << reason << ")\n";
        } else {
            std::cerr << "[cmd] " << cmd << " FAILED — no ACK, TV state not changed ("
                      << reason << ")\n";
        }
        return ok;
    };

    monitor->setOnCommand([&](const TvCommand& c) {
        const char* cmd = c.on ? "ON" : "OFF";
        return report(cmd, c.reason, transport->send(cmd));
    });

#ifdef __linux__
    bool bootOnPending = false;
#endif

    monitor->setOnDeviceChange([&](bool present) {
        if (!present) {
            transport->invalidate();
            return;
        }
#ifdef __linux__
        // Delivers the boot ON when the stick enumerates after the daemon starts.
        if (bootOnPending && systemJustBooted()) {
            bootOnPending = !report("ON", "device ready", transport->send("ON"));
        }
#endif
    });

#ifdef __linux__

    if (systemJustBooted()) {
        bootOnPending = !report("ON", "startup", transport->send("ON"));
        if (bootOnPending) {
            std::cout << "[cmd] ON deferred until the ESP32 appears\n";
        }
    } else {
        std::cout << "[cmd] ON skipped — service restarted on an already-running "
                     "system, not a boot\n";
    }
#endif

#ifdef _WIN32

    if (console) {
        std::cout << "[sys] Console mode — checking the ESP32 responds, then exiting\n";
        const bool ok = report("ON", "console check", transport->send("ON"));
        return ok ? 0 : 1;
    }
#endif

    std::cout << "[sys] Daemon running\n";
    monitor->run();

    return 0;
}

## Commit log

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2026-04-02 Phase 2 — USB HID transport with ACK-based inhibitor lock release
    - Firmware: replaced CDC Serial with vendor HID, fires IR then sends ACK/ERR
    - Daemon: HIDTransport finds ESP32 by VID/PID, blocks on ACK before releasing lock
    - Removed fixed 500ms delay — lock released only after IR confirmed transmitted
    - Graceful handling when ESP32 unplugged — daemon starts cleanly, system never blocked
    - HID test program verified two-way communication before integration
    - Daemon installed as systemd service
    [main.cpp]
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2026-04-04 Revert to OLED "Waiting..." after command confirmation
    After sending the ACK, show TV On/Off for 2s then return to Waiting...
    Also reverts abandoned NeoPixel attempt (BAT LED is hardware-controlled).
    [main.cpp]
2026-04-07 Update brief for Phase 3 scope
    Documents full Phase 3 design decisions:
    - Button behaviour (GPIO 5): press/hold/cycle/config/factory reset
    - OLED states and display always-on setting
    - WiFi AP config mode and web UI
    - Multi-manufacturer profile storage on LittleFS (JSON)
    - PING/PONG daemon liveness detection
    - Factory reset via button or web UI
    - Full web UI scope with Save/Restore/Factory Reset/Save and Exit
2026-04-07 Phase 3 step 1 — LittleFS profile storage and PING/PONG
    - Add Profiles module: LittleFS JSON storage for manufacturer profiles
    and device settings. Writes defaults on first boot, supports factory
    reset from hardcoded defaults.
    - Default profiles: LG (confirmed codes), Samsung/Sony/TCL/Hisense
    (placeholder codes).
    - IR dispatch now uses active profile protocol and codes instead of
    hardcoded LG NEC values.
    - Add PING command handler in firmware — responds PONG immediately.
    - Daemon HIDTransport recognises PONG response.
    - Display turns off after ON/OFF confirmation (Phase 3 idle = display off).
    - Add ArduinoJson to platformio.ini, set filesystem = littlefs.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
    [Profiles.cpp, main.cpp]
2026-04-07 Phase 3 steps 2-4 — Button, Display, profile cycling
    - Button: non-blocking press/hold detection with debounce. Press = release
    within 300ms. Hold drives progress bars at 300ms, config threshold at 5s,
    reset countdown at 8s, auto factory reset at 23s.
    - Display: state-managed OLED with timed expiry. States: off, status,
    IR confirm, hold bar (5-block), reset bar (15-segment), WiFi lock message.
    - Profile cycling: first press = PING + show status, second press = cycle
    to next visible profile. pressCount resets when display turns off or hold begins.
    - WiFi mode toggle wired to config threshold (WiFi start/stop in step 6).
    - Display always-on setting respected throughout.
    Co-Authored-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
    [main.cpp]
2026-04-07 Fix button/display logic and add daemon PING background reader
    Firmware fixes:
    - pressCount now resets via display.onExpire when STATUS timer expires,
    so a press after display turns off is correctly treated as first press
    - Display module tracks wifiActive_ state, shows "WiFi: Active" third line
    when in WiFi mode (3-line layout at y=0/11/22)
    - onConfigThreshold calls display.setWifiActive() so WiFi line appears immediately
    - WiFi mode press 1 now calls pingDaemon() and refreshes status screen
    - pingDaemon() simplified — no txBuf+1 offset, shows Waiting before sending
    Daemon fix:
    - HIDTransport: background reader thread polls every 50ms for input reports.
    Responds to PING with PONG i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
    [main.cpp]
2026-04-07 Phase 3 button/display fixes and brief update
    - Fix onConfigThreshold never firing (configFired_ set during hold blocked release)
    - Fix factory reset bar freezing display after auto-trigger (guard heldMs >= 23000)
    - PING only on first press after display was off — config/reset/hold-cancel
    all set pressCount=1 so subsequent presses cycle profiles
    - Brief updated: PING rule documented, hold cancellation behaviour added,
    roadmap updated with completed Phase 3 items
    [main.cpp]
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2026-04-08 Code review fixes and cleanup
    - Fix potential buffer overrun in firmware HID command parsing
    (null-terminate rxBuf after memcpy)
    - Fix stale dev_ after second write failure in daemon HIDTransport
    (close and null on retry failure)
    - Update Project Outline to remove PING/PONG references
    - Move SerialTransport to daemon/archive/ (retained for non-HID reuse)
    [main.cpp]
2026-04-08 Phase 3 steps 6-7 — WiFi AP, web server, and web UI
    - WiFi soft AP (ESP32-IR-Remote) with start/stop wired to button hold
    - WebServer on port 80 with JSON API for profiles, settings, factory
    reset, and exit
    - Static file serving from LittleFS for web UI
    - Single-page web UI: profile CRUD, active selection, visibility toggle,
    display always-on setting, restore/save/factory reset/save & exit
    - Brief updated with Phase 3 progress
    [main.cpp]
2026-04-14 Code cleanup and project outline update
    - Remove dead Display::lastAlwaysOn_ field (written, never read)
    - Remove unused alwaysOn/profileName params from showHoldBar
    - Add Profiles::replaceAll() — replace const_cast hack in profiles POST handler
    - Extract finishExitWifi() helper to deduplicate WiFi-exit cleanup across button,
    factory reset, and deferred web-UI exit paths
    - Factory reset via web UI now also exits WiFi mode (consistent with button reset)
    - OLED shows live AP IP address in WiFi mode (pulled from WiFi.softAPIP())
    - Web UI shows "Changes take effect after saving" info line
    - Web UI save triggers immediate OLED refresh
    - Remove stale Phase 1/2/3 comments from source files
    - Pr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
    [Profiles.cpp, main.cpp]
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2026-08-13 put correct 3d modeling directory in
    [0.91in OLED.STEP, ESP32-Remote-Housing.FCStd, ESP32-Remote-Housing.stl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]
2026-08-14 Bug fix pass — 12 fixes, verified on hardware
    Full review of the Phase 1-3 code. The architecture held up and needed no
    redesign; the issues were robustness gaps at the edges — corrupt input, a
    missing device, unusual OS events. The worst were not crashes but failures
    that reported themselves as successes.
    Correctness:
    - Daemon logged "ACK received" for commands that never happened. An
    unplugged ESP32, a failed write and an expired timeout all reported
    success. ITransport::send() now returns bool.
    - Daemon log output never reached the journal. std::cout is fully buffered
    when stdout is not a terminal, which is the case under systemd; the
    shutdown OFF confirmation was lost outrig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
    [Profiles.cpp]
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2026-08-23 Second hardening pass — 9 fixes, redundancy removed
    Three of the first pass's fixes had closed the reported instance without
    closing the class it belonged to. This pass closes them.
    Fixes:
    13 A late ACK was accepted as the next command's reply. hidraw queues input
    reports, so a reply that arrived after send() gave up satisfied the next
    command's read. The protocol gains a sequence byte, echoed by the firmware;
    the daemon discards unmatched replies and drains the queue before writing.
    14 writeJsonAtomic promoted a short write — it checked against zero rather
    than measureJson(), so a partial document could be renamed over a good one.
    15 PrepareForShutdown(false) never r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
2026-08-23 Restructure the outline — group by subject, distil fixes into invariants
    924 -> 798 lines, but the point is the shape rather than the size. The
    document was four documents in one: a spec, a build runbook, a bug log and
    an inventory, interleaved so none of them read well. The build instructions
    that save the most time were buried 400 lines down.
    Now grouped by subject, with a contents index at the top since it is still
    one long file: Overview, Current status, Hardware, Architecture, Protocol,
    Firmware, Daemon, Invariants, Building, Known issues, History.
    The 21-row fix tables are gone, replaced by an Invariants section. Going
    through them, roughly 12 encoded a rule worth keeping and 9 wer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
2026-08-24 Drop the phase numbering left orphaned by the restructure
    Removing the Roadmap section took the definitions of Phase 1/2/3 with it,
    but references to them survived in two places in the brief and four code
    comments — labels pointing at a scheme the reader can no longer look up.
    Dropped rather than redefined. All three phases are complete, so the numbers
    only ever carried meaning relative to a plan that has been executed; what a
    reader needs now is what a thing *is*, not which stage delivered it.
    ITransport.h "SerialTransport — USB CDC Serial, Phase 1"
    -> "HIDTransport — USB HID; the one that is compiled in"
    "SerialTransport — USB CDC serial;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
2026-08-24 Stop tracking FreeCAD backups and mesh exports
    FreeCAD writes a .FCBak beside the master on every save, so they accumulate
    and churn without ever being the file anyone wants. Mesh exports are derived
    from the .FCStd and go stale the moment the model changes.
    Both were showing up as untracked noise on every status, and one .FCBak had
    already been committed at some point — removed here. It was deleted from the
    working tree already; this just makes the repo agree.
    The .FCStd master and the .STEP component models stay tracked.
    Also restores the CAD tracking policy to the brief, as a short section under
    Hardware. The earlier restructure dropped the File Structure entry that
    carried it, which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
2026-08-24 Record second-pass hardware verification
    Flashed firmware and filesystem on 2026-08-24 and exercised the daemon
    against the real device. Splits the old "unverified" list into what has now
    actually been observed and what genuinely has not.
    Verified: udev on hotplug, device retry at boot, the sequenced protocol,
    sleep, wake, shutdown, boot, and the uptime gate in both directions
    (skipped on `systemctl restart`, sent on a genuine boot).
    The shutdown path is the notable one — the journal shows the inhibitor
    holding systemd off until the ESP32 ACKed, then the unit stopping. That is
    the design premise working under a real poweroff rather than inferred from
    a suspend.
    Still unverified: cancell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
2026-08-24 Drop the cancelled-shutdown handling
    Removes fix 15 from the second hardening pass. PrepareForShutdown(false)
    goes back to doing nothing.
    The fix closed a real lock leak, but the edge case it guards is far
    narrower than it first appeared. The delay inhibitor is only released once
    the shutdown has actually begun, and the daemon drops it within about a
    second of that — measured at 02:10:17 to 02:10:18 in the journal. So the
    window in which a cancel can leave the lock released is sub-second. Cancel
    during the scheduled wait beforehand, which is what anyone would actually
    do, and no signal has fired at all: nothing was released, nothing leaks.
    The same reasoning applies to the TV. It is not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
2026-08-24 Record the 0x0 guard as verified; accept corrupt-storage recovery untested
    Samsung selected with its codes still 0x0: the OLED showed "Not Configured"
    and nothing was transmitted, instead of putting a meaningless frame on the
    air and answering ACK. That closes the last fix from the second pass that
    was on the reporting-honesty path — the whole point of the guard was that a
    placeholder profile stops claiming success.
    Corrupt /profiles.json recovery moves from the todo list to a new "Accepted
    untested" section. The path exists and is reasoned about, but exercising it
    means building and flashing a deliberately corrupt LittleFS image, and the
    case it guards is both rare and cheap to recover f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
2026-08-24 Add a Windows work plan to the brief
    Windows is the current focus, so the outstanding work moves from a
    three-row backlog entry to a section that says what actually has to
    change, where, and what has to be decided first.
    Corrects two claims. Windows was never "confirmed working" — that was a
    typo in an early version and is now recorded as false so it cannot
    resurface. And the Windows status section claimed a robust implementation
    was "available later without touching anything else", which is wrong:
    main.cpp needs a boot gate and a logging destination, HIDTransport needs
    platform-sized timeouts, and CMakeLists has no Windows install path at all.
    Documents the sleep asymmetry as an accepte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
2026-08-24 Record the settled Windows decisions
    Five of six settled: rewrite both WindowsPowerMonitor files keeping the
    Win32 boilerplate verbatim, handle PBT_APMRESUMEAUTOMATIC only, run as
    LocalSystem until tested then move to LocalService, sc create now with an
    MSI at first release, restart on failure with a 5s delay.
    The resume-event choice corrects the plan rather than just filling it in.
    The changes table said "both events plus a dedup flag"; AUTOMATIC is
    documented as firing on every resume and RESUMESUSPEND is additional, for
    user-initiated wakes only, so handling AUTOMATIC alone covers every case
    with no dedup state. Less code, and one fewer thing to get wrong.
    Account and install both follo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
2026-08-24 Settle on a worker thread; record gaps against a commercial product
    Threading model decided: control handlers push and return, one worker
    thread does the send.
    The deciding argument was not "by the book" but coupling. Blocking would
    have been safe only because the send is bounded at ~1.5s — and that bound
    lives in HIDTransport.cpp while the code depending on it lives in
    WindowsPowerMonitor.cpp, connected by nothing but a comment. The budget is
    already marked as needing measurement, so it will change, and when it does
    nothing complains. Same shape as fix 11 and fix 16: an invariant nothing
    enforces. A single worker also serialises sends by construction, so no
    mutex is needed after all.
    Ad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
2026-08-24 Compile both platforms on every push
    The Windows sources had never been compiled once, and nothing would have
    noticed if they stopped compiling: the packaging jobs only ran on a v* tag
    and neither touched Windows. A broken tree was discoverable at release time
    at the earliest.
    Two compile-only jobs, no artifacts. Their whole job is to fail loudly when
    the half of the tree nobody builds locally stops building.
    The deb and rpm jobs are now gated on a v* ref, since the workflow fires on
    branch pushes too. Note this does not close the release guard: a v* tag still
    publishes packages while the VID/PID are placeholders.
    Claude-Session: https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
2026-08-24 Create the Windows service with New-Service, not sc.exe
    sc.exe parses its own command tail rather than going through
    CommandLineToArgvW, so binPath= must arrive already quoted when the path
    contains a space. Getting a quoted string through PowerShell's native-argument
    handling intact is unreliable, and the failure it produces is a service that
    installs cleanly and then fails to start with an error naming the wrong cause.
    New-Service takes the path as a real parameter. The stored value stays quoted
    deliberately — an unquoted service path containing a space is the classic
    unquoted-service-path weakness.
    Claude-Session: https://claude.ai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
2026-08-24 Name the device that was opened, and why a write failed
    Symptom on Windows: the console check works repeatedly, then after an unplug
    and replug fails repeatedly, then works again after another replug. The logs
    could not distinguish the causes, because "Write failed" was all they said.
    hid_open(vid, pid, NULL) takes whichever device the OS enumerated first. The
    placeholder 1234:5678 are common hobbyist defaults, already recorded as a
    release blocker for exactly this reason, and enumeration order is not stable
    across a replug. A collision would present as intermittency that follows
    replugs rather than time, which is the observed shape. On Linux the udev rule
    meant only one device was ever rea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
    [main.cpp]
2026-08-24 Dump the report descriptor the host parsed when a write fails
    The device-selection code from the previous commit was not the cause: the two
    HIDClass entries on the Windows machine are one physical ESP32 presenting as
    a USB parent node and its HID child, which is the normal device tree. There
    is no VID/PID collision on that machine.
    What remains is a handle that opens cleanly and then fails every write, until
    a replug. Windows derives the required output-report length from the parsed
    report descriptor and rejects writes that do not match, and it caches that
    parse against the device instance — so a descriptor fetched while the device
    was not ready produces exactly this: persistent across pr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
2026-08-24 Recover USB state in firmware after a suspend
    The root cause of the intermittent Windows write failures. When the host
    suspends the bus, this device comes back mounted but stops servicing its OUT
    endpoint: hid_open succeeds and every write then fails on a completion
    timeout, until the device is physically re-enumerated.
    It is not a Windows defect. Linux hid it because its daemon holds the device
    open continuously, so an idle device is never suspended — a difference in host
    behaviour, not in ours. Anything that suspends the bus reaches it.
    The device cannot distinguish a wedged OUT endpoint from an idle one; both are
    silence. So rather than detecting the bad case, the firmware stops trust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
    [main.cpp]
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2026-08-26 Cover all three Windows power models, and say which one this is
    The display-state design already covered S3, hibernate and Modern Standby
    behaviourally — one mechanism, with the suspend and resume events as secondary
    triggers. What it could not do was tell anyone which of the three had produced a
    given log, or notice the device it talks to coming and going. Both start
    mattering the moment the testing spans more than one machine, which it now does.
    The capability report is the load-bearing part. CallNtPowerInformation is read
    once at startup and logged, because without it a log is ambiguous in a way no
    amount of reading the events resolves: an absent PBT_APMSUSPEND is a defect on
    an S3 des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
    [main.cpp]
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2026-08-26 Stop three decisions being applied past where they hold
    A review of the settled decisions against each other rather than against the
    code. All three of these were correct about the path they were written for and
    wrong one step further out, which is the same shape as the finding the History
    section already records: a fix that closes the case in front of it without
    closing the class it belongs to.
    **The startup fallback asserted ON when no display state arrived.** The brief
    dismissed the risk as "wrong only for a service restart that happens while the
    display is off" — but that is precisely the 3am case the uptime gate exists to
    prevent on Linux and that PBT_APMRESUMEAUTOMATIC is deliberate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
    [main.cpp]
2026-08-26 Carry the deadline with the event, and scope the display-off OFF
    A second pass over the settled decisions, asking a different question from the
    one the last pass asked. That pass read the decisions against each other and
    found three that had been generalised past the path they were written for. This
    one reads them against the Overview — not "is this consistent?" but "does this
    still deliver the four rows in the table this device exists for?" It found two
    more, and they are the two that were hardest to see from inside the decision
    list, because both looked correct until the product was the yardstick.
    **The time budget was attached to an event class rather than to an event.**
    IPowerMonitor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
    [main.cpp]
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2026-09-09 Add a firmware watchdog, and rewrite the brief around the display
    The watchdog is the last defect that could make the device silently stop
    working. Nothing on the PC side can tell a hung stick from an unplugged one, so
    a hung loop() would persist until somebody noticed the TV had stopped following
    the PC — precisely the failure this device exists to beat. A reset recovers
    cleanly: profiles live in flash and the daemon reopens on its next send.
    20s is sized by the web server rather than by anything in our own code. A single
    handleClient() can legitimately block around 12s if a client stalls — 5s for the
    request, 5s for data to be ACKed, 2s for the close — while everything else in
    loop(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
    [main.cpp]
2026-09-09 Move the USB identity to pid.codes' test PID
    1234:5678 was made up. 1209 is pid.codes, a vendor ID held in trust for
    open-source hardware, and 0001 under it is their designated test PID — meant
    for a device under development that has no product ID of its own yet.
    Three things this buys. The vendor half is a real allocation rather than a squat
    on somebody else's identity; anyone who recognises it knows it is a placeholder;
    and the eventual fix is a PID-only change, because applying to pid.codes is a
    free pull request under the same VID.
    It is not a release identity. pid.codes ask that products are not distributed on
    the test PID, since several devices in development can carry it. That is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
    [main.cpp]
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2026-09-09 Fill in the Samsung, Sony and Toshiba codes, and fix Sony's bit length
    Takes the working profile set from one to four. Every code is derived from
    irdb's protocol/device/OBC parameters through the same encoder the firmware
    links against, rather than copied as hex off a forum, so the bit ordering cannot
    disagree with what IRremoteESP8266 will transmit.
    The check that makes this trustworthy: irdb's LG entry (NEC1, device 4, OBC
    196/197) reproduces 0x20DF23DC and 0x20DFA35C exactly — the codes already proven
    on real hardware here. Same source, same method, same answer.
    Sony was also broken independently of its codes. SIRC has 12-, 15- and 20-bit
    forms and a TV is category 1, the 12-bit one;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
    [Profiles.cpp, main.cpp]
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2026-09-09 Tidy the repository layout, and unbreak the Arch package
    No path in the tree contains a space any more. "3D modeling/" becomes
    "hardware/" and "HID test/" becomes "tools/hid-test/", along with three CAD
    files. Spaces in paths are not cosmetic: every script, CMake path and CI step
    has to quote them, and the one that gets forgotten fails in a way that is
    tedious to trace.
    DEPRECATED/ and daemon/archive/ are deleted. Both are in git history. The
    archived serial transport was not free to keep — it needed a hand-patch when
    ITransport changed earlier today, despite nothing ever compiling it, which is
    the whole argument against carrying deferred code in the tree.
    VERSION moves to the repository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
    [0.91in-OLED.STEP, ESP32-Remote-Housing.FCStd, ESP32-S3_Zero.step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]
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2026-09-11 Wait for the ESP32 to arrive instead of missing the boot ON
    The boot ON regressed when the transport was changed to fail fast on an
    unenumerated device. Every other caller recovers through reopenBefore(),
    which only runs after a handle that was already open stops working — at
    boot there was never a handle, so the ON was dropped. The stick is powered
    by the machine that is booting and is still running setup() while systemd
    starts the daemon.
    Linux now subscribes to udev for hidraw arrivals and matches the VID/PID by
    walking up to the owning usb_device. run() polls the sd-bus fd and the udev
    fd together rather than calling enterEventLoop(), so there is no second
    thread and no lock on the tr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
    [main.cpp]
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
